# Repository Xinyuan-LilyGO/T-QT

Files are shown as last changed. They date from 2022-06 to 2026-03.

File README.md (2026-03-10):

<h1 align = "center"> 🌟T-QT🌟</h1>

## Description

T-QT is a development board whose main control chip is ESP32-S3. It is equipped with a 0.85-inch LCD color screen and two programmable buttons. Retains the same layout design as T-Display. You can directly use ESP32S3 for USB communication or programming.

***
## Pinmap

!!! There are currently two chip versions, using ESP32S3-FN4R2 (4MB Flash, 2MB PSRAM) and ESP32S3-N8 (8MB Flash, No PSRAM), the following only shows the pin diagram of N4R2, and the pin diagram of N8 is the same.

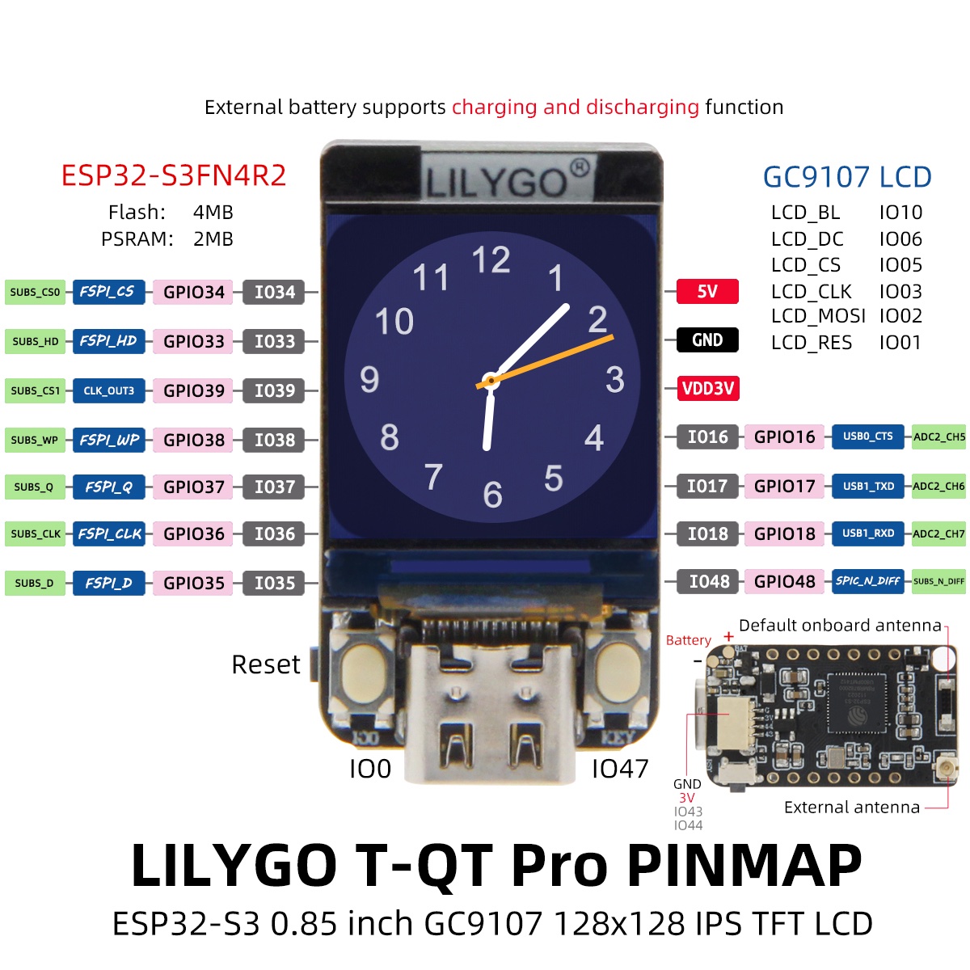
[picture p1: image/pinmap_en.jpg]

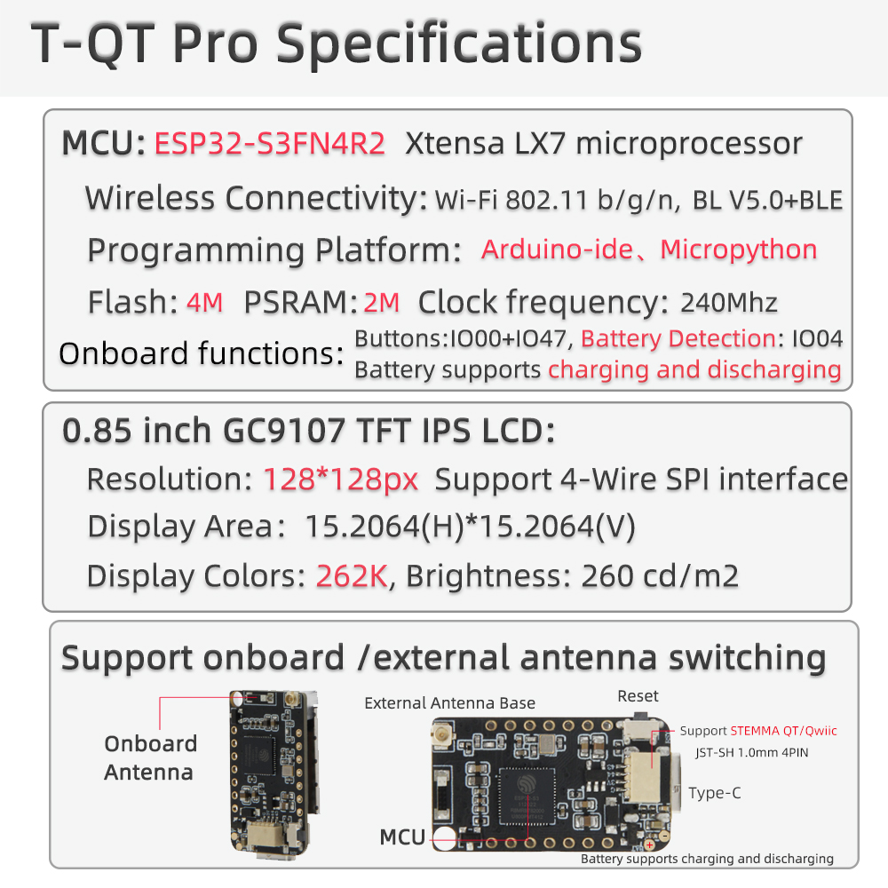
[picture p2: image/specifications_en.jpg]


***
<h3 align = "left">Product 📷:</h3>

| Product  | Product Link |
| :---: | :---: |
| T-QT Pro | [AliExpress](https://www.aliexpress.com/item/1005004405292321.html) |
| T-QT Pro | [LilyGo](https://www.lilygo.cc/products/t-qt-pro) |

***
## Quick Start

> Arduino:
1. In Arduino Preferences, on the Settings tab, enter the `https://raw.githubusercontent.com/espressif/arduino-esp32/gh-pages/package_esp32_index.json` URL in the `Additional boards manager URLs` input box. **Please pay attention to the version. The test phase is using 2.0.14. It is not certain that versions above 2.0.14 can run. When the operation is abnormal, please downgrade to a version below 2.0.14.** , As of 2024/08/02, TFT_eSPI does not work on versions higher than 2.0.14, see [TFT_eSPI/issue3329](https://github.com/Bodmer/TFT_eSPI/issues/3329)
2. Click OK and the software will install. 
3. Search for ESP32 in Tools → Board Manager and install ESP32-Arduino SDK (version 2.0.3 or above)
4. Copy everything from this repository lib folder to [Arduino library folder](https://docs.arduino.cc/software/ide-v1/tutorials/installing-libraries#manual-installation) (e.g. `C:\Users\YourName\Documents\Arduino\libraries`)
5. Select the correct settings in the Tools menu as shown below.

    ### K192,H579,H590 , 4M Flash , 2M PSRAM

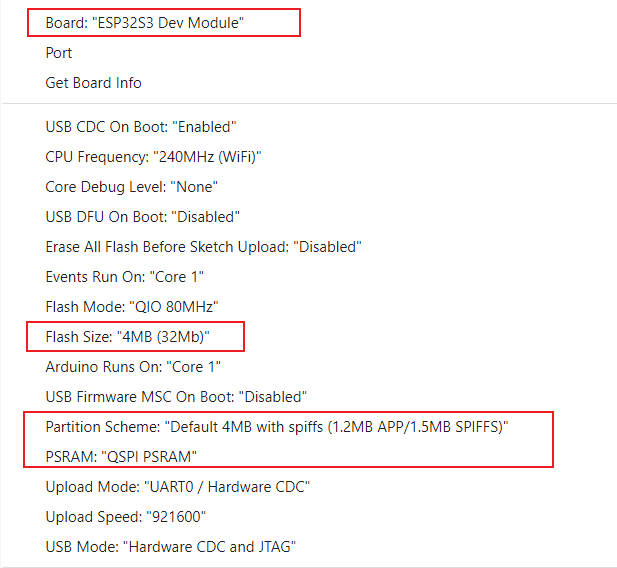
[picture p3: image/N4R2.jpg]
    

    ### K191,H628,H588 , 8M Flash ,No PSRAM

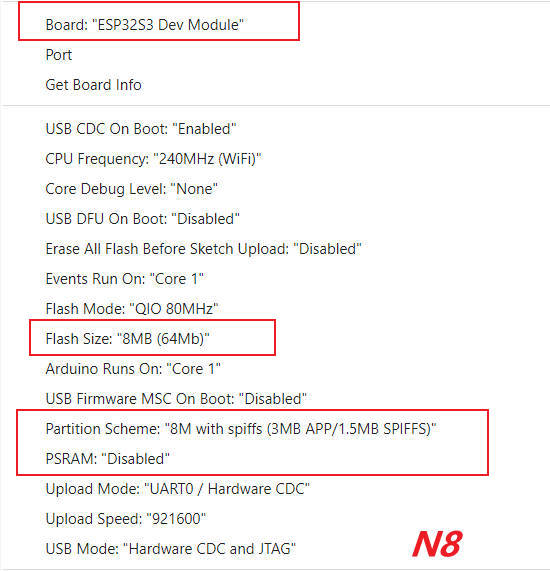
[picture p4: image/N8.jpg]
    

> PlatfromIO:
> - PlatformIO plug-in installation: Click on the extension on the left column -> search platformIO -> install the first plug-in
> - Click Platforms -> Embedded -> search Espressif 32 in the input box -> select the corresponding firmware installation

> ESP-IDF:
> - The installation method is also inconsistent depending on the system, it is recommended to refer to the [official manual](https://docs.espressif.com/projects/esp-idf/en/latest/esp32/get-started/index.html) for installation

***
## Quick question and answer

1. Does the onboard lithium battery charge function?
   - The old version T-QT does not support charging
   - The version on sale T-QT Pro supports charging function

2. Is it normal for the chip to continue to heat up during use?
   - The ESP32S3 will continue to heat up during use. Due to the small size of the baseboard, the heat of the ESP32S3 cannot be dissipated in time, so the overall temperature is stable at about 50-60 degrees Celsius. This temperature does not affect the normal use of the chip.

3. Unable to write?
   -  Press and hold the BOOT button on the board (located on the left side of the front of the screen), keep it tight, then plug in the USB and click to upload the sketch

## Tips

- The program can be written normally, but there is still no display after writing
    1. There are factory test files in the firmware folder, which can be flashed into the board to check whether the board is normal. If there is still no display, then it can be judged that there is a problem with the board or the screen
    2. Delete the <TFT_eSPI> in the libraries, and replace the <TFT_eSPI> in the <lib> folder of the main page to the libraries directory
    3. When opening the Arduino IDE, it prompts whether to upgrade the library, please choose not to upgrade, otherwise it will overwrite the configuration of the <TFT_eSPI> display

- Please note that the current use is a copy of TFT_eSPI, the screen initialization parameters have been modified, if you use the initialization parameters of the main line branch, the screen will not be clear

- QT currently sells two types of displays. The default configuration in lib/TFT_eSPI is the latest version. If you encounter display issues, please switch to the previous version's configuration:
- Here are the replacement steps: 

- Old panel
  1. Copy extras/old_panel/GC9A01_Init.h to lib/TFT_eSPI/TFT_Drivers. When prompted to overwrite, select yes. This will revert the display configuration to the old version initialization.
  2. Copy extras/old_panel/GC9A01_Rotation.h to lib/TFT_eSPI/TFT_Drivers. When prompted to overwrite, select yes. This will revert the display configuration to the old version initialization.

- New panel
  1. Copy extras/new_panel/GC9A01_Init to lib/TFT_eSPI/TFT_Drivers. When prompted to overwrite, select yes. This will revert the display configuration to the new version initialization.
  1. Copy extras/new_panel/GC9A01_Rotation to lib/TFT_eSPI/TFT_Drivers. When prompted to overwrite, select yes. This will revert the display configuration to the new version initialization.

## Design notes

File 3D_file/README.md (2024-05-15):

# This is 3D Shell File

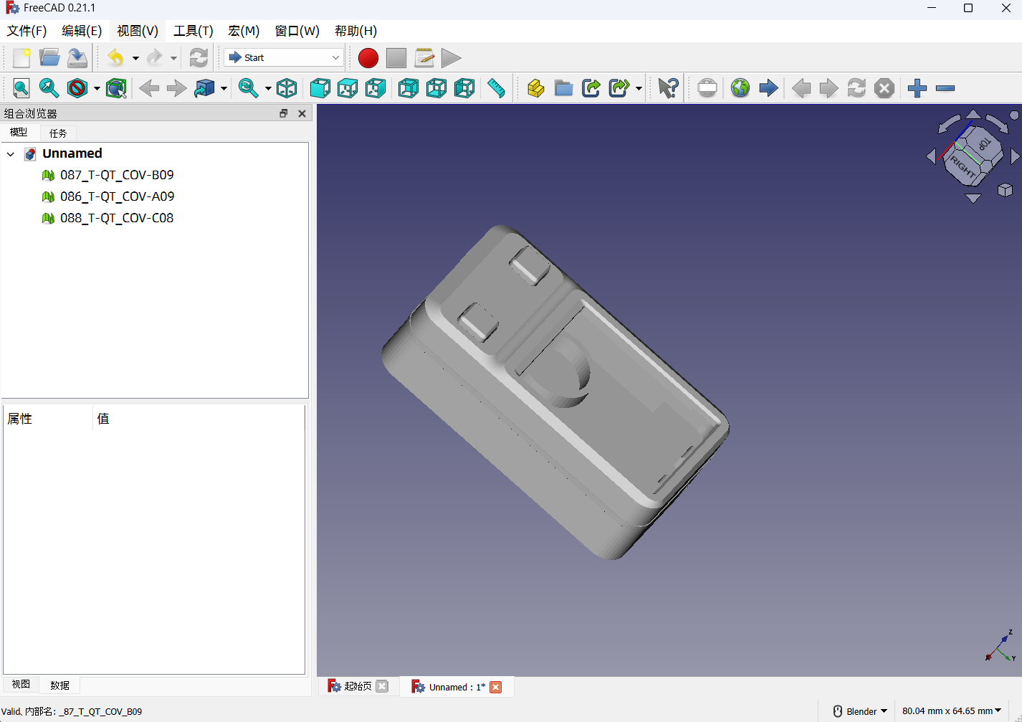
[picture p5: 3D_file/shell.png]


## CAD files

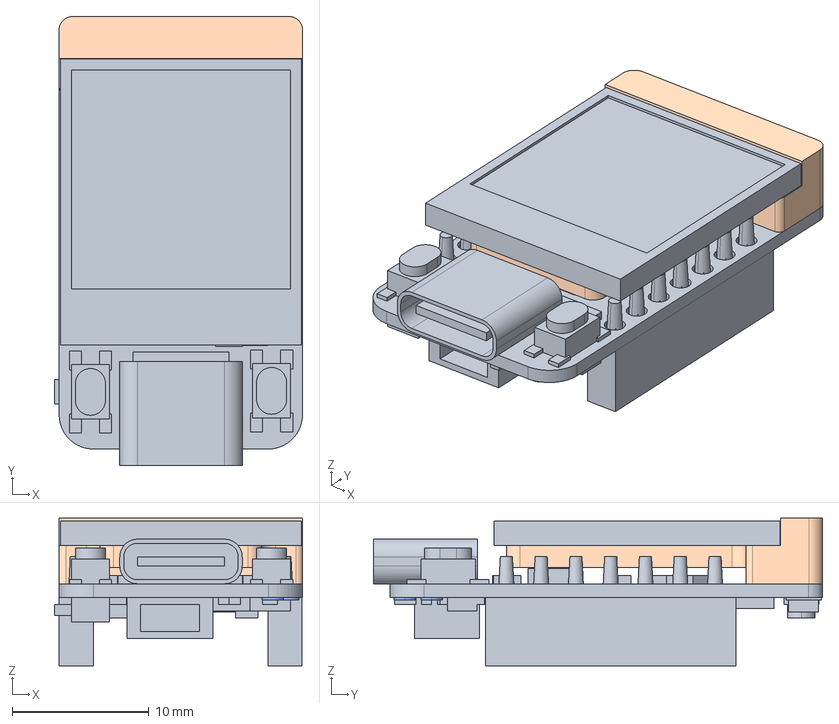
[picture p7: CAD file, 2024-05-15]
3D_file/T_QT_Pro.stp
18.1 x 32.8 x 10.8 mm
T_Q1T-PCB
050_T_Q1T-PMMA-COV5
T-Q1T-LCD
T_Q1T-PCB-00

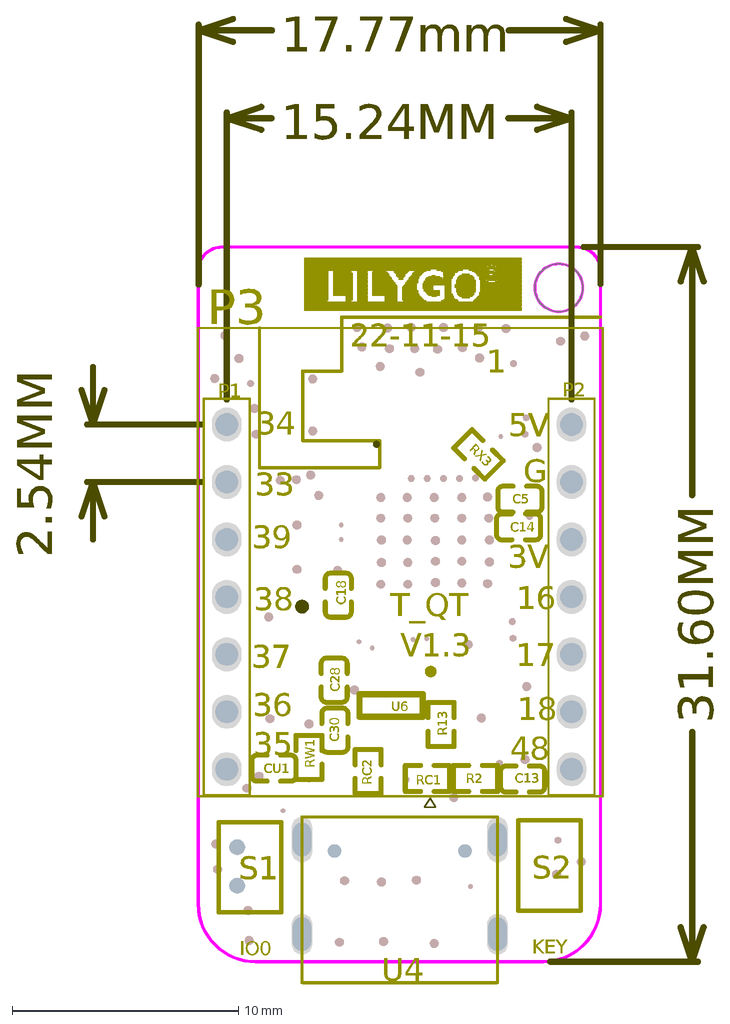
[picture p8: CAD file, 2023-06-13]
3D_file/T_QT.DXF
22-11-15
V1.3
T_QT
KEY
IO0
1
34
33
39
38
37
36
35
5V
G
3V
16
17
18
48
2.54MM
31.60MM
17.77mm
15.24MM
P2
P1
U4
S2
S1
RX3
RW1
R2
CU1
C18
C14
C13
C5
C28
C30
U6
P3
R13
RC1
RC2

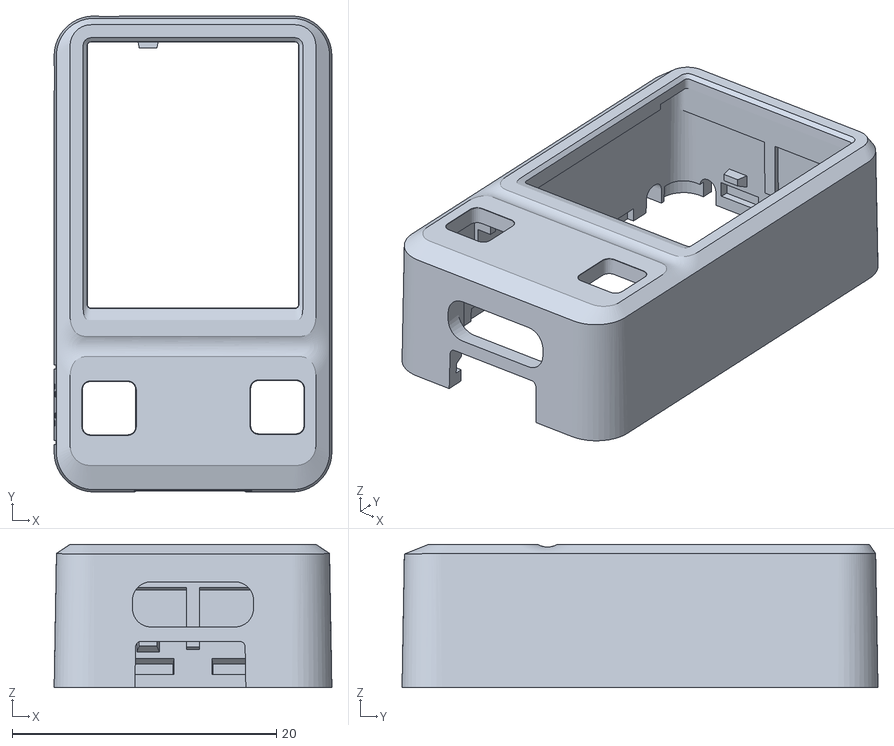
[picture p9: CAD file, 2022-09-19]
3D_file/086_T-QT_COV-A09.stl
21.0 x 36.0 x 10.9

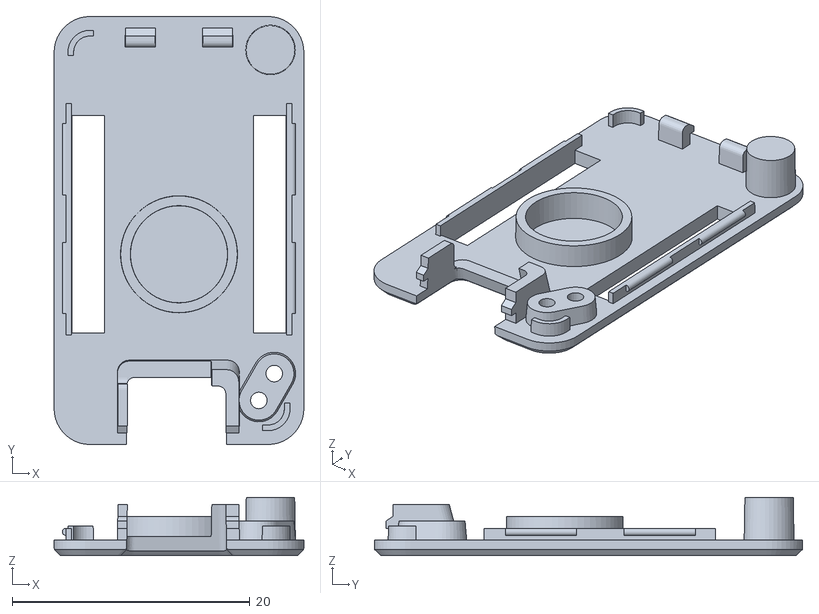
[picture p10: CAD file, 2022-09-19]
3D_file/087_T-QT_COV-B09.stl
21.0 x 36.0 x 4.90

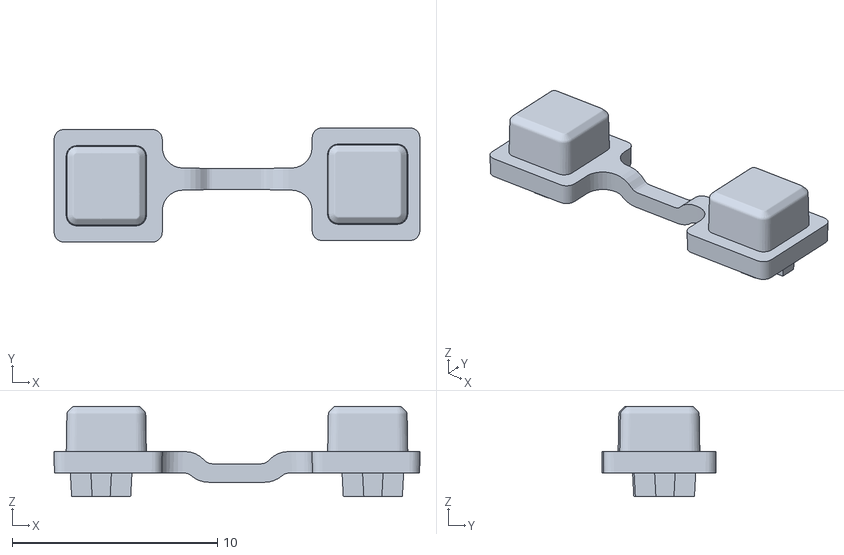
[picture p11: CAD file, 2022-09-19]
3D_file/088_T-QT_COV-C08.stl
17.8 x 5.57 x 4.40

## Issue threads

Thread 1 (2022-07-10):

There's no units available anywhere!

Sarah-C, 2022-07-10:
What happened?

We've got the code here, (thanks!) but the device is no longer available.  =(

Sarah-C, 2022-07-11:
I can't find the T-QT anywhere online anymore. It's only been for sale a short time.

You don't happen to know a link I can use to buy it, do you?

Sarah-C, 2022-07-12:
https://www.aliexpress.com/item/1005004405292321.html

Finally - they're back in stock today!

Closed 2022-07-12.

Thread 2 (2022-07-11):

Board Manager URL  error

Vadimledyaev, 2022-07-11:
Hi, Arduino ide can not load your boards package :
https://raw.githubusercontent.com/espressif/arduino-esp32/gh-pagespackage_esp32_index.json

This url leads to **400: Invalid request** page

What is the correct url?
Thanks

LilyGO, 2022-07-13:
The URL in the description may have expired, please use a new URL

https://raw.githubusercontent.com/espressif/arduino-esp32/gh-pages/package_esp32_index.json

Vadimledyaev, 2022-07-14:
Thanks! The guide does not say which board should I choose?
There are plenty of boards available from the list **Tools - Boards - ESP32 -** .
Which one is yours?

Sarah-C, 2022-07-24:
It'll be the : ESP32-S3 Dev Board         

[Vadimledyaev](https://github.com/Vadimledyaev), be careful with the libraries!    
TFT_eSPI's current version does NOT compile with the Factory demo. 

For me, I don't use the library else where, so I just deleted it from my library folder, and copied https://github.com/Xinyuan-LilyGO/T-QT/tree/main/lib libraries into my lib folder.      

The alternative is a bit messier - copying the libraries from this github into the sketch Factory folder, flat. No subfolders. Then you can use the up to date versions in your other libraries.

I don't know what changed so much to break it - I didn't spend time looking at the errors. =/

JpEncausse, 2022-07-30:
Hi,
There is no ESP32-S3 Dev Board I choose Dev Module but got `Error compiling for board ESP32S3 Dev Module` I correctly copy /lib to Arduino /librairies folder
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

Sarah-C, 2022-07-31:
My mistake, as you saw, it's "Module"

@JpEncausse
"Error compiling for board ESP32S3 Dev Module"..... there'll be more red/error text further up the text box. Can you dig it out? It'll detail file file name, line number, the line of code, and a little ^ arrow pointing to where it saw the issue.

JpEncausse, 2022-07-31:
Unfortunatly I didn't get more details, I assume it can't check for the given board,
Can you detail the Arduino option to set for T-QT ? (Memory, etc ...) to be sure I set evrything correctly (I tried many but still get the error)

LilyGO, 2022-08-02:
You just need to check "ESP32S3 Dev module" and the correct port. PSRAM needs to select OPI mode. Other configurations can be configured or set by default according to your project needs.

JpEncausse, 2022-08-02:
Ok so here is my configuration :

**OS**
- Windows 11
- Arduino 1.8.19
- Copy T-QT-main/lib/* into C:\Users\{name}\Documents\Arduino\libraries

First error : The Factory example didn't run because the script look for lv_conf.h that must be in /librairies/lv_conf.h I copy it from elswhere. Now it is fixed

**Arduino**
- Board : ESP32 Dev Module
- Upload Speed : 115200
- USB Mode : Hardware CDC and JTAG
- USB CDC On Boot : Disabled
- USB Firmware MSC On Boot : Disabled
- CPU Frequency : 240MHz (wifi)
- FlashMode : OPI 80MHz
- FlashSize : 8MB (64Mb)
- Partition Scheme : Default 4Mb with spiffs
- Core Debug Level : None
- PSRAM : OPI PSRAM
- Arduino Run on Core 1
- Events Run on Core 1
- Port COM4

Error 2 : So the `factory` and `lcd` script now compile but the board failed at reboot error with esptool (I assume the program is correctly write). On the board side, the screen stay black ...

LilyGO, 2022-08-05:
My mistake, I mistakenly thought this was a T-Display-S3. The PSRAM setting should be changed to QSPI or DISENABLE. (It depends on whether you bought the version with PSRAM or not). But selecting DISENABLE should be no problem.

LilyGO, 2022-08-05:
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

lynema, 2022-08-06:
After following this directions and compiling the factory example using the Arduino IDE and ESP32 library version 2.0.4, these lines are repeated over and over.

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

Board: ESP32S3 Dev Module
Libraries were copied from the demo so the TFT library has the right config
USB A to C cable was used as well.  The program uploaded.

Are there other settings that are missing that need to be set?

LilyGO, 2022-08-06:
Please try to use ESP32 library version 2.0.4. And execute the simplest blink program to test the hardware function of the board. If the blink program runs normally, please use this routine: https://github.com/Xinyuan-LilyGO/T-QT/tree/main/example/lcd @lynema

lynema, 2022-08-06:
@LilyGO
Tried this sketch with ESP32 library version 2.0.4.
```
void setup() {
	Serial.begin(115200);
}

void loop() {
	Serial.printf("Hello World");
	delay(3000);
}
```

Same thing happened.  The hardware is good.  When it was initially plugged in, the on-board display showed that it was attempting to connect to a wifi access point.

```
07:01:51.008 -> ESP-ROM:esp32s3-20210327
07:01:51.008 ->
07:01:51.115 -> ESP-ROM:esp32s3-20210327
07:01:51.115 -> Build:Mar 27 2021
07:01:51.115 -> rst:0x7 (TG0WDT_SYS_RST),boot:0x8 (SPI_FAST_FLASH_BOOT)
07:01:51.115 -> Saved PC:0x400454d5
07:01:51.148 -> SPIWP:0xee
07:01:51.148 -> mode:QIO, clock div:2
07:01:51.148 -> load:0x3fce3808,len:0x43c
07:01:51.148 -> ets_loader.c 78
```

lynema, 2022-08-07:
It works under platform.io with a couple edits.

These lines need to be altered to account for case sensitivity in https://github.com/Xinyuan-LilyGO/T-QT/blob/main/example/factory/platformio.ini
[env:esp32-s3-devkitc-1]
board = esp32-s3-devkitc-1
The board is esp32-s3-devkitc-1 which is different than what was mentioned above as the board name to try in the Arduino IDE. https://docs.platformio.org/en/latest/boards/espressif32/esp32-s3-devkitc-1.html

LilyGO, 2022-08-10:
@lynema Sorry, I rechecked my platformIO configuration. I am using arduino 2.0.3. version. Please recompile with this version.

LilyGO, 2022-08-10:
2.0.4 seems to have upgraded some features causing a reset, but I haven't checked its logs yet.

lynema, 2022-08-11:
@LilyGO Both
platform_packages = framework-arduinoespressif32@https://github.com/espressif/arduino-esp32.git#2.0.3
and
platform_packages =  framework-arduinoespressif32@https://github.com/espressif/arduino-esp32.git#2.0.4
worked ok for me.

Vadimledyaev, 2022-08-11:
After a few days of trying to hook the device up to my PC(Windows10,  Arduini IDE 2) without success (probably a problem with drivers but even Zadig couldn't fix that) I managed to make it on my laptop. After that I tried a pretty fresh windows 10 virtual machine under my main one and that works, too.

So after all Arduino is working, confirmed.

"SHA-256 comparison failed:" error is kinda normal:
```
SHA-256 comparison failed:
Calculated: 080c5cb68a075ced55f248b97bca965e3e5bd5da80a64e34e6a1638f89d6f64e
Expected: ffffffffffffffffffffffffffffffffffffffffffffffffffffffffffffffff
```

P.s, in case you haven't worked with lvgl lib like I haven't, To make it work you must copypaste lv_conf.h provided by LiLyGO to a LIB folder, do not leave it as is in  "lib/lvgl/"!

Sarah-C, 2022-08-20:
>P.s, in case you haven't worked with lvgl lib like I haven't, To make it work you must copypaste lv_conf.h provided by LiLyGO to a LIB folder, do not leave it as is in "lib/lvgl/"!

Good to know! Thanks!

I've had the exact same issue with a couple of other boards on my desktop Vs laptop. ....... how curious....

ChrisJones79, 2022-11-17:
Using the USB-OTG board works for me but I had to zip the lib I wanted to use and added the file image.h to the sketch

lewisxhe, 2023-03-29:
Not active for a long time, will be closed

ChrisJones79, 2023-03-29:
Ok

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

Closed 2023-03-29.

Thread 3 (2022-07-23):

../../lv_conf.h: No such file or directory

Sarah-C, 2022-07-23:
I've just run the "factory" example... and I get this:

            from C:\Users\sarah\Documents\Arduino\sketches\T-QT\factory\factory.ino:5:
c:\users\sarah\documents\arduino\libraries\lvgl\src\lv_conf_internal.h:41:18: fatal error: ../../lv_conf.h: No such file or directory
#include "../../lv_conf.h" /Else assume lv_conf.h is next to the lvgl folder/
^~~~~~~~~~~~~~~~~
compilation terminated.

Sarah-C, 2022-07-23:
Ah, I used the current lv library, I copied the one supplied in this code and it works fine.

Closed 2022-07-23.

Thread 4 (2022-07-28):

Bought 3 - 0 work

disruptivepatternmaterial, 2022-07-28:
Can someone tell me what the magic is to get these to work? I am using a Mac and tried multiple USB-C cables. None of the units power up or appear available in PIO.

What is the secret?

mgsb, 2022-07-28:
I had the same problem. What works for me is to use a USB-A cable on the host side, even if it means a USB-C/USB-A adaptor for the host. I asked elsewhere for LILYGO feedback but have not heard anything, yet.

LilyGO, 2022-08-02:
Please use a USBA-USBC cable. The use of USBC-USBC is not currently supported.

Closed 2022-08-10.

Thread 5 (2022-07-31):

Hour hand doesn't move as it should... fix included

Sarah-C, 2022-07-31:
If you're finding the hour hand in the factory demo to be a bit wonky... here's the fix.

The hour hand doesn't increment in fractions, so if it's 5 to 3, it looks almost like 5 to 2 because the hour hand hasn't moved on!

The fix shows the hour hand correctly positioned between two numbers for half past the hour:

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

The fix adds on the angle of the minutes scaled to 1/12 of a circle to the angle of the hour hand... which is simply multiplying the minutes by 5.

lvgl_gui.cpp
```
void update_sensor(lv_timer_t *timer) {
  float volt = (analogRead(PIN_BAT_VOLT) * 2 * 3.3) / 4096;
  char buf[20];
  snprintf(buf, 20, "bat_volt:%.2f V", volt);
  lv_label_set_text(bat_label, buf);

  struct tm timeinfo;
  if (getLocalTime(&timeinfo)) {
    // The line that fixes the hour hand.
    lv_img_set_angle(hour_img, ((timeinfo.tm_hour) * 300 + ((timeinfo.tm_min) * 5)) % 3600);
    lv_img_set_angle(min_img, (timeinfo.tm_min) * 60);
```

LilyGO, 2022-08-02:
thanks for your reminder.Please submit a pull request and I'll merge this.

Sarah-C, 2022-08-06:
https://github.com/Sarah-C/T-QT/commit/2980144b879a394d9c9399973fc774039b7895f6

[Micky513673326](https://github.com/Sarah-C/T-QT/commits?author=Micky513673326) has been nice enough to submit the pull request. Thank you!

Issue closed.

Sarah-C, 2022-08-06:
Closed!

Closed 2022-08-06.

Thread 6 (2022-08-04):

No CC Resistor

seldompopup, 2022-08-04:
Board connecting to USB-C port directly using USB-C to USB-C cable will not receive power.

LilyGO, 2022-08-05:
We also noticed issues with USBC. A fix for this resistor will be added in the next release.

Closed 2022-08-10.

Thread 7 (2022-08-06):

Waking up on right button - doesn't happen.

Sarah-C, 2022-08-06:
I see that the right button puts the device to sleep - which works fine.             
However I note that esp_sleep_enable_ext0_wakeup is used to set the wake button to the same right button.    
This doesn't work either via a build in Arduino (latest regular build) nor in PlatformIO - the device stays off.

I've no idea where the error is, it doesn't look like it's how it's being used here - perhaps Espressifs own code?      
I'm just raising this issue for others to know it's a "known issue" - and not this codes fault.

main.cpp:
```

void go_to_sleep(void) {
  Serial.println("sleep");
  digitalWrite(PIN_LCD_BL, HIGH);
  gpio_hold_en((gpio_num_t)PIN_LCD_BL);
  digitalWrite(PIN_LCD_RES, LOW);
  esp_sleep_enable_ext0_wakeup((gpio_num_t)PIN_BTN_R, 0);
  esp_light_sleep_start();
}
```

[What pins can wake the device.](https://docs.espressif.com/projects/esp-idf/en/v4.1/api-reference/peripherals/gpio.html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,DAC%2Fetc%20are%20in%20use.)

[The pins labelled RTC compatible.](https://docs.espressif.com/projects/esp-idf/en/latest/esp32s3/api-reference/peripherals/gpio.html)

The left button is GPIO 0, and the right is GPIO 47, so I originally thought it wasn't waking due to GPIO47 not being a RTC pin (and thus unable to wake the device) as shown in the article above.
I swapped the pin numbers in pin_config.h, because GPIO 0 IS connected to the RTC. But this failed to wake the device either.

```
#define PIN_BTN_L            47
#define PIN_BTN_R            0

```

Gargantuanman, 2022-10-14:
Im having the same issu thats because for some reason the PULL UP of the pin 0 fall when you send the controller to deepsleep that shouldnt be happening i believe there is some error on the schematic because supposely the button isn pulled up directly to regulator out, so it should be 3.3v always.

mmMicky, 2023-01-30:
As far as I know ESP32-S3 has this problem. You can use esp_sleep_enable_ext1_wakeup instead.

afpineda, 2023-02-09:
> Im having the same issu thats because for some reason the PULL UP of the pin 0 fall when you send the controller to deepsleep that shouldnt be happening i believe there is some error on the schematic because supposely the button isn pulled up directly to regulator out, so it should be 3.3v always.

Despite being externally pulled-up, maybe the GPIO is disabled before entering deep sleep mode. Check this code:

```c
void enterDeepSleep()
{
  // disable radios
  esp_bluedroid_disable();
  esp_bt_controller_disable();

  // Disable pins to avoid current drainage through pull resistors
  // Enable proper pull resistors for wake up (if available)
  for (int p = 0; p < GPIO_NUM_MAX; p++)
    if (GPIO_IS_VALID_GPIO((gpio_num_t)p) && !((p >= 6) && (p <= 11))) // Exclude flash memory pins
    {
      uint64_t pinBitmap = BITMAP(p);
      if (pinBitmap & ext1_wakeup_sources)
      {
        if (ext1_wakeup_mode == ESP_EXT1_WAKEUP_ANY_HIGH)
        {
          gpio_pullup_dis((gpio_num_t)p);
          gpio_pulldown_en((gpio_num_t)p);
        }
        else
        {
          gpio_pulldown_dis((gpio_num_t)p);
          gpio_pullup_en((gpio_num_t)p);
        }
      }
      else
      {
        gpio_pulldown_dis((gpio_num_t)p);
        gpio_pullup_dis((gpio_num_t)p);
      }
    }

  // enter deep sleep
  if (ext1_wakeup_sources != 0ULL)
  {
    ESP_ERROR_CHECK(esp_sleep_pd_config(ESP_PD_DOMAIN_RTC_PERIPH, ESP_PD_OPTION_ON));
    ESP_ERROR_CHECK(esp_sleep_enable_ext1_wakeup(ext1_wakeup_sources, ext1_wakeup_mode));
  } // else reset is required for wake up
  esp_deep_sleep_start();

  // should not enter here
  log_e("power::powerOff(): Deep sleep not working");
  delay(5000);
  ESP.restart();
}
```

`ext1_wakeup_sources` and `ext1_wakeup_mode` are global variables. `ext1_wakeup_sources` is a bitmap of configured GPIO numbers to be used for wake up.

```c
// Power management
static uint64_t ext1_wakeup_sources = 0;
static esp_sleep_ext1_wakeup_mode_t ext1_wakeup_mode = ESP_EXT1_WAKEUP_ANY_HIGH;
```

[Source code](https://github.com/afpineda/OpenSourceSimWheelESP32/blob/main/src/common/power.cpp)

lewisxhe, 2023-03-29:
I discovered this issue during yesterday's reorganization and has now fixed it

Sarah-C, 2023-06-27:
lewisxhe - this was a PCB routing change?

Closed 2023-03-29.

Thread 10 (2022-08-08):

Factory clock color

kirk5275, 2022-08-08:
How can I change the colors of the clock? Background, hands etc.?

kirk5275, 2022-08-09:
My Display is mostly gray with white letters. Second hand is yellowish orange.

LilyGO, 2022-08-09:
please attach your picture

kirk5275, 2022-08-09:
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

No matter what camera I use the is a blue tint to the picture. I see all gray with my eyes.

kirk5275, 2022-08-09:
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
Here is a better representation.

kirk5275, 2022-08-09:
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

LilyGO, 2022-08-10:
Abnormal display color is generally caused by several problems.
1. RGB and BGR display format settings are wrong.
2. The order of sending color buf is reversed.
3. The colors are set to invert.

  Select a normal color image to convert to an array and display the image using the provided TFT_eSPI library. If the display is normal, record the picture display format as RGB or BGR. reconstruct

kirk5275, 2022-08-10:
Just want to say that the duck looks okay. Green background white duck yellow beak and orange feet.

I am using your factory example with no modifications. Why should I have to change anything to get the colors to come out correctly? Also I don't know how to do do what you told me.

Again might I have a bad unit?

LilyGO, 2022-08-13:
If duck color is green background white duck yellow beak and orange feet. Then its color is normal.

kirk5275, 2022-08-15:
Okay. I might have wasted your time and you mine. The one with blue clock is in \T-QT-main\lib\TFT_eSPI\examples\Smooth Graphics\Anti-aliased_Clock.

LilyGO, 2022-08-15:
This obviously has nothing to do with the hardware. It may just be that a register needs to be modified during initialization or that it needs to be high first when sending color BUF.

kirk5275, 2022-08-15:
I am closing this as I don't have a color problem

Closed 2022-08-15.

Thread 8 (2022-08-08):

Programming with PlatformIO

kirk5275, 2022-08-08:
In order to program I have to hold reset, hold IO0, release IO0 and release IO0. Then click on the upload icon in PlatformIO to get it to program.

I have a ESPRESSIF ESP32-S3-DevKitC-1 board and I don't have to touch anything. PlatformIO works using the same code

LilyGO, 2022-08-09:
T-QT is uploaded via USB. If you want to view serial information through USB, you need to enable USB CDC on Boot in the Arduino configuration page. If you need to add a flag in platformIO:
build_flags =
     -DARDUINO_USB_MODE=1
     -DARDUINO_USB_CDC_ON_BOOT=1

kirk5275, 2022-08-09:
I'm sorry but that was not my question. I am talking about uploading code. To Upload I have to do the following:
1. Press and hold reset
2. Press and hold IO0
3. Release reset
4. Release IO0
5. Click on upload icon in PlatformIO

I do not have to do those steps if I use a  ESP32-S3-DevKitC-1 dev board from ESPRESSIF

I do see it executing a reset when it says connecting as my device does reboot. But it never goes into programming mode.

Uploading .pio\build\esp32-s3-devkitc-1\firmware.bin
esptool.py v3.3
Serial port com13
Connecting...  <-----------------------------------------------------------------**(RESETS HERE)**
Traceback (most recent call last):
Failed to get PID of a device on com13, using standard reset sequence.
  File "C:\Users\krkjc\.platformio\packages\tool-esptoolpy\esptool.py", line 5387, in <module>

    _main()
  File "C:\Users\krkjc\.platformio\packages\tool-esptoolpy\esptool.py", line 5380, in _main
    main()
  File "C:\Users\krkjc\.platformio\packages\tool-esptoolpy\esptool.py", line 4687, in main
    esp = esp or get_default_connected_device(ser_list, port=args.port, connect_attempts=args.connect_attempts,
  File "C:\Users\krkjc\.platformio\packages\tool-esptoolpy\esptool.py", line 115, in get_default_connected_device
    _esp.connect(before, connect_attempts)
  File "C:\Users\krkjc\.platformio\packages\tool-esptoolpy\esptool.py", line 664, in connect
    last_error = self._connect_attempt(mode=mode, usb_jtag_serial=usb_jtag_serial, extra_delay=extra_delay)
  File "C:\Users\krkjc\.platformio\packages\tool-esptoolpy\esptool.py", line 629, in _connect_attempt
    self.sync()
  File "C:\Users\krkjc\.platformio\packages\tool-esptoolpy\esptool.py", line 519, in sync
    val, _ = self.command(self.ESP_SYNC, b'\x07\x07\x12\x20' + 32 * b'\x55',
  File "C:\Users\krkjc\.platformio\packages\tool-esptoolpy\esptool.py", line 458, in command
    self.write(pkt)
  File "C:\Users\krkjc\.platformio\packages\tool-esptoolpy\esptool.py", line 421, in write
    self._port.write(buf)
  File "C:\Users\krkjc\.platformio\penv\lib\site-packages\serial\serialwin32.py", line 325, in write
    raise SerialTimeoutException('Write timeout')
serial.serialutil.SerialTimeoutException: Write timeout
*** [upload] Error 1
========================================== [FAILED] Took 101.61 seconds ==========================================

 *  The terminal process "C:\Users\krkjc\.platformio\penv\Scripts\platformio.exe 'run', '--target', 'upload'" terminated with exit code: 1.
 *  Terminal will be reused by tasks, press any key to close it.

LilyGO, 2022-08-10:
When you turn on the USB-CDC feature in settings. The next uploader can continue to use the port without pressing the button again. I have tested this function. The premise requires that you turn on the USB CDC on Boot function and do not use this pin in the program.

kirk5275, 2022-08-10:
I have these set in Platform.ini
build_flags =
    ;-DARDUINO_USB_MODE=1
    ;-DARDUINO_USB_CDC_ON_BOOT=1

I am trying to upload the factory (clock) example. It does NOT work. I get the error in my previous post.
Using those settings does enable the Serial Monitor to work.

I am the one that is also having color issues. Could I have  bad hardware?

kirk5275, 2022-08-15:
Anything movement on this issue of not having to press buttons to upload in PlatformIO?

LilyGO, 2022-08-15:
I didn't need to press IO0 for every download like you did during PlatformIO development. I have stated that this flag needs to be added and do not do anything with the USB pins in the code.

build_flags =
-DARDUINO_USB_MODE=1
-DARDUINO_USB_CDC_ON_BOOT=1

If you think the board has a color problem. Please upload a TFT example and upload a picture for me to observe.

kirk5275, 2022-08-15:
I found I don't have a color problem the factory clock is only gray background.

I have set the build flags to what you told me. I am not doing anything with the USB pins. Like I said I can see the device doing a reset when it says connecting.

I have attached the simplest program to output on the serial port "Testing". It does not upload without me pressing buttons.

If you have a sketch you want me to try I will
[upload test.zip](https://github.com/Xinyuan-LilyGO/T-QT/files/9335727/upload.test.zip)
.

kirk5275, 2022-08-15:
I also tried the same code with Aurduino IDE with the following settings and it won't upload either

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

Sketch uses 233217 bytes (17%) of program storage space. Maximum is 1310720 bytes.
Global variables use 13152 bytes (4%) of dynamic memory, leaving 314528 bytes for local variables. Maximum is 327680 bytes.
esptool.py v3.3
Serial port COM13
Connecting...Traceback (most recent call last):
  File "esptool.py", line 5387, in <module>
  File "esptool.py", line 5380, in _main
  File "esptool.py", line 4687, in main
  File "esptool.py", line 115, in get_default_connected_device
  File "esptool.py", line 664, in connect
  File "esptool.py", line 629, in _connect_attempt
  File "esptool.py", line 519, in sync
  File "esptool.py", line 458, in command
  File "esptool.py", line 421, in write
  File "serial\serialwin32.py", line 325, in write
serial.serialutil.SerialTimeoutException: Write timeout
[26460] Failed to execute script 'esptool' due to unha
ndled exception!
Failed uploading: uploading error: exit status 1

Sarah-C, 2022-08-20:
The T-QT device works correctly when commanded to reset. I can confirm it works with PlatformIO:
```
Building .pio\build\adafruit_feather_esp32s3_nopsram\firmware.bin
esptool.py v3.3
Creating esp32s3 image...
Merged 2 ELF sections
Successfully created esp32s3 image.
Configuring upload protocol...
AVAILABLE: cmsis-dap, esp-bridge, esp-builtin, esp-prog, espota, esptool, iot-bus-jtag, jlink, minimodule, olimex-arm-usb-ocd, olimex-arm-usb-ocd-h, olimex-arm-usb-tiny-h, olimex-jtag-tiny, tumpa
CURRENT: upload_protocol = esptool
Looking for upload port...
Auto-detected: COM10
Forcing reset using 1200bps open/close on port COM10
Waiting for the new upload port...
Uploading .pio\build\adafruit_feather_esp32s3_nopsram\firmware.bin
esptool.py v3.3
Serial port COM24
Connecting...
Chip is ESP32-S3
Features: WiFi, BLE
Crystal is 40MHz
MAC: f4:12:fa:43:20:b4
Uploading stub...
Running stub...
Stub running...
Changing baud rate to 460800
Changed.
Configuring flash size...
Flash will be erased from 0x00000000 to 0x00003fff...
Flash will be erased from 0x00008000 to 0x00008fff...
Flash will be erased from 0x0000e000 to 0x0000ffff...
Flash will be erased from 0x002d0000 to 0x002f8fff...
Flash will be erased from 0x00010000 to 0x0005ffff...
Flash params set to 0x023f
Compressed 15008 bytes to 10328...
Writing at 0x00000000... (100 %)
Wrote 15008 bytes (10328 compressed) at 0x00000000 in 0.3 seconds (effective 344.9 kbit/s)...
Hash of data verified.
Compressed 3072 bytes to 128...
Writing at 0x00008000... (100 %)
Wrote 3072 bytes (128 compressed) at 0x00008000 in 0.1 seconds (effective 303.4 kbit/s)...
Hash of data verified.
Compressed 8192 bytes to 47...
Writing at 0x0000e000... (100 %)
Wrote 8192 bytes (47 compressed) at 0x0000e000 in 0.1 seconds (effective 486.7 kbit/s)...
Hash of data verified.
Compressed 165488 bytes to 106746...
Writing at 0x002d0000... (14 %)
Writing at 0x002d863e... (28 %)
Writing at 0x002ddbbf... (42 %)
Writing at 0x002e4585... (57 %)
Writing at 0x002ea540... (71 %)
Writing at 0x002efe98... (85 %)
Writing at 0x002f529d... (100 %)
Wrote 165488 bytes (106746 compressed) at 0x002d0000 in 1.9 seconds (effective 700.1 kbit/s)...
Hash of data verified.
Compressed 326224 bytes to 169379...
Writing at 0x00010000... (9 %)
Writing at 0x00020d00... (18 %)
Writing at 0x00029f32... (27 %)
Writing at 0x00031e71... (36 %)
Writing at 0x0003786b... (45 %)
Writing at 0x0003cc00... (54 %)
Writing at 0x00041ec5... (63 %)
Writing at 0x00047780... (72 %)
Writing at 0x00050fb2... (81 %)
Writing at 0x00057f07... (90 %)
Writing at 0x0005d9a0... (100 %)
Wrote 326224 bytes (169379 compressed) at 0x00010000 in 3.3 seconds (effective 779.5 kbit/s)...
Hash of data verified.

Leaving...
Hard resetting via RTS pin...
```

OP please check your device drivers, as the device correctly reboots into upload mode when commanded to by PlatformIO, without any user involvement.

kirk5275, 2022-08-20:
@Sarah-C Thanks for the suggestions. I tried it on a laptop computer and it worked. Play around with the USB drivers and got it working on the desktop computer.

LilyGO, 2022-08-22:
https://github.com/Xinyuan-LilyGO/T-QT/issues/8#issuecomment-1215669544
As your Arduino is set up, turn on CDC ON BOOT

kirk5275, 2022-08-22:
I tried it on a laptop computer and it worked. Played around with the USB drivers and got it working on the desktop computer.
FYI you don't need these flags to upload. Only for the Serial Monitor to work. I just tried it.

 ;-DARDUINO_USB_MODE=1
 ;-DARDUINO_USB_CDC_ON_BOOT=1

Everything is working okay.

Sarah-C, 2022-08-22:
You're welcome! Happy coding!

evlo, 2023-01-26:
So could I connect RX TX to the usb data lines, keep 5V and GND and usb to work with uart like that?

Closed 2022-08-20.

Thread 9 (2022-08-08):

Serial Monitor

kirk5275, 2022-08-08:
How do I get the serial monitor to work with PlatformIO?

Using this simple program:

void setup() {
	Serial.begin(9600);
}

void loop() {
	Serial.printf("Hello World");
	delay(3000);
}

I get this:
--- Terminal on COM13 | 9600 8-N-1
--- Available filters and text transformations: colorize, debug, default, direct, esp32_exception_decoder, hexlify, log2file, nocontrol, printable, send_on_enter, time
--- More details at https://bit.ly/pio-monitor-filters
--- Quit: Ctrl+C | Menu: Ctrl+T | Help: Ctrl+T followed by Ctrl+H
waiting for download

Works okay with ESPRESSIF ESP-S3-DevKitC-1 board.

kirk5275, 2022-08-09:
Found the answer

build_flags =
    -DARDUINO_USB_MODE=1
    -DARDUINO_USB_CDC_ON_BOOT=1

Closed 2022-08-09.

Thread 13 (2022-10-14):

display backlight doesent remain OFF when deepSleep

Gargantuanman, 2022-10-14:
Currently Im executing this piece of code:

 if (goToSleep) {
    //Serial.println("I need to Sleep");
    gfx->displayOff();
    digitalWrite(TFT_BL, HIGH); // turn  OFF
    ledcWrite(pwmLedChannelTFT, 255);           // brightness 0 - 255
    esp_deep_sleep_start();
  }

I noticed that the screen backlight turns off brieftly but when the micro sleeps it turn on again (only Back light) i believe is because of the default state of the pin is LOW, is therea a workaround this issue?

The battery will dryout quickly if the BL cannot turn off.

Gargantuanman, 2022-10-14:
SOLVED just included this library and used those two commands.

#include "esp_sleep.h"

if (goToSleep) {
    //Serial.println("I need to Sleep");
    gfx->displayOff();
    digitalWrite(TFT_BL, HIGH); // turn  OFF
    gpio_hold_en(GPIO_NUM_10);
    gpio_deep_sleep_hold_en();
    esp_deep_sleep_start();
  }

Closed 2022-10-14.

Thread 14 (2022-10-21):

Publish board settings for Arduino IDE

HowdyMoto, 2022-10-21:
Can you please publish what settings I should use here in the Arduino IDE?
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

LilyGO, 2022-10-26:
Just select ESP32-S3-DEV. Most of the other options vary based on individual usage.

mmMicky, 2022-11-23:
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

afpineda, 2023-02-09:
Note:

In order to **enter boot mode**, press and hold the `IO0` button while pressing the `RESET` button.

MichaelCastano, 2023-05-01:
> Note:
>
> If required, in order to **enter boot mode**, press and hold the `IO0` button while pressing the `RESET` button.

Had problems connection on Windows 11 and that one hint solved it for me in the end 👍  Thanks
On MacOs it worked right out of the box following the Lilygo instructions.

Closed 2023-03-29.

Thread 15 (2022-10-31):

T-QT Pro?

dskw, 2022-10-31:
Hi, I have noticed that a lot of stores offer a "T-QT Pro" version instead of V1.1.
The only difference I could find is this image:
https://ae01.alicdn.com/kf/S24bd6ed3ecd24f09878124b287e865efs.jpg_640x640Q90.jpg_.webp

Is there an updated repository for the Pro version?
What does "support charging" mean? Does it allow LiPo charging?

LilyGO, 2022-11-01:
>Is there an updated repository for the Pro version?
There are no new warehouses. They share a repository, the only difference is the difference in hardware (psram and flash size)

>What does "support charging" mean? Does it allow LiPo charging?
Yes, it supports lithium battery charging.

dskw, 2022-11-01:
Thank you for the clarification! I would suggest to add a short section to the readme.rm to describe the new version. The added lithium battery charging makes the board even more attractive! :)

Vadimledyaev, 2023-01-29:
Hi, what cha

Closed 2022-11-01.

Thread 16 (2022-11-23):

What settings for factory example?

matterbury, 2022-11-23:
With the default settings compilation fails with:
```
Sketch uses 1379037 bytes (105%) of program storage space. Maximum is 1310720 bytes.
Global variables use 41472 bytes (12%) of dynamic memory, leaving 286208 bytes for local variables. Maximum is 327680 bytes.
```
With Flash Size of 8MB (64 Mb) and Partition Scheme 8M with spiffs the device just crash reboots.

matterbury, 2022-11-23:
In fact it would be very helpful to have some idea of which examples work on the T-S3 board and what settings are needed for them. So far I'm about 3 for 8 working with the rest just blank screen or crash booting.

mmMicky, 2022-11-23:
T-QT is a flash size of 8M. T-QT PRO has 4M flash size and 2M PSRAM. You can set the partition table for storing programs slightly larger. E.g 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

mmMicky, 2022-11-23:
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

matterbury, 2022-11-23:
Thanks, but as far as I can tell the factory example just does not work on the T-S3.
Many of the TFT_ ones do so I can play with those.

mmMicky, 2022-11-24:
It works fine on my computer. I wonder why your run fails. I need to fix it.

mmMicky, 2022-11-25:
I suggest you take a screenshot of the error or setting. I can help you check the problem.

mmMicky, 2022-11-25:
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
Here you need to set none

matterbury, 2022-11-25:
I set PSRAM to none and all the other settings as you have above.
Here is a video of the device while uploading, then a flash of the previous (clock) app when it rebooted, then the apparent crash looping after booting: https://www.dropbox.com/s/mhblk9lckomdqxq/IMG_0240.MOV?dl=0

Thanks for your help.

mmMicky, 2022-11-26:
I thought you had a problem with the T-QT product. If you have a problem with T-Display-S3, you need to enable the PSRAM-OPI function. It is recommended that you clone the repository without modifying it and use platformIO to compile. Because I used this platform to make. So I recommend you to use it.

mmMicky, 2022-11-26:
I can put the tested binary bin firmware here for you to burn and test.
[bin.zip](https://github.com/Xinyuan-LilyGO/T-QT/files/10095440/bin.zip)

matterbury, 2022-11-26:
Thank you very much, OPI PSRAM did the trick!

Closed 2022-11-26.

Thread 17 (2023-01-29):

Qwiic connector's pinout is wrong.

tfuruha, 2023-01-29:
The pinout(and The GPIO numbers printed) of the Qwiic connector are wrong, unlike the connections on the schematic.
According to the [ESP32-S3 datasheet](https://github.com/Xinyuan-LilyGO/T-QT/blob/main/doc/esp32-s3_datasheet_en.pdf), U0TXD and GPIO43 and U0RXD and GPIO44 each share a pin.
On the [schematic](https://github.com/Xinyuan-LilyGO/T-QT/blob/main/schematic/T_QT.pdf), pin 3 of the Qwiic connector is connected to U0TXD (GPIO43), but printed as 44 on the board and [pinout](https://github.com/Xinyuan-LilyGO/T-QT/blob/main/image/pinmap_en.jpg).
I2C tests using the Qwiic connector also worked fine by setting SDA (3pin) to 43 and SCL (4pin) to 44.

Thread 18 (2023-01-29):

T-QT PRO circuit and charging IC

Vadimledyaev, 2023-01-29:
Hi,

1. what charging IC is used in PRO version?
2. What is the charging current limit? I think it should be set to something like 20-30mA. Otherwise, a small battery will not last long.
3. Can you update the schematic pdf and provide the printed circuit of the PRO version?

Thanks.

mmMicky, 2023-01-30:
The charging IC used is TP4065. The charging current is limited to 400-500mA. I can update the schematic PRO version.

Vadimledyaev, 2023-01-30:
Well that current will definitely kill a small (60-200mAh +) battery and probably may cause **fire** and **explosion** . I strongly do not suggest to use it with a 1000mAh or less battery. (which size is huge).

For those who wanted a wearable device - desolder TP4065 and replace it with LTC4054 which charges the battery with currents from 10mA to 150mA (with Rprog set to 1000/Icharge, Ω, so from 100KΩ to 33KΩ is ok)

Weird and dangerous decision. Not supposed to be used in a wearable device. Liligo should kick in his butt the person who made the update without letting the people know the current.

mmMicky, 2023-01-31:
Adjust the charging current if necessary. No need to replace the chip. Only the current limiting resistor needs to be replaced. It's not always at 500mA charge when charging. When the battery voltage reaches about 4V, it will enter the trickle charging state. For specific correlation curves, please refer to the manual.

Vadimledyaev, 2023-01-31:
> Adjust the charging current if necessary. No need to replace the chip. Only the current limiting resistor needs to be replaced. It's not always at 500mA charge when charging. When the battery voltage reaches about 4V, it will enter the trickle charging state. For specific correlation curves, please refer to the manual.

According datasheet, TP4065 Charging current is from 130mA to 1A. That means even if I replace the resistor, the charging current of 130mA is still too high for a small,  wearable device. It will destroy a 80mAh battery, sooner or later. But yeah, It might be ok for a big 200mAh ++ battery if you replace the resistor .

Vadimledyaev, 2023-03-01:
> The charging IC used is TP4065. The charging current is limited to 400-500mA. I can update the schematic PRO version.
HI, when would you update the schematic circuit?

lewisxhe, 2023-03-29:
Not active for a long time, will be closed

dskw, 2023-06-01:
> The charging IC used is TP4065. The charging current is limited to 400-500mA. I can update the schematic PRO version.

The schematic has not been updated, or anything else on the repo. It still does not even mention the QT-Pro and its charging capabilities.

@Vadimledyaev could you tell which resistor on the boards needs to be replaced and with which resistance or achieve 150mA charging current? I was not able to find an English manual for TP4065 yet ;(

lewisxhe, 2023-06-01:
@dskw  When I saw your message, I verified that there is indeed an error. I have changed the schematic diagram and related materials to T-QT Pro, and the different sizes of resistors I noted in the schematic diagram correspond to different charging currents. . PS: I am not the designer of T-QT, I have tried my best to make the schematic diagram easy to understand
https://github.com/Xinyuan-LilyGO/T-QT/blob/main/schematic/T-QT-Pro.pdf

dskw, 2023-06-01:
@lewisxhe ahh perfect, thank you :) You even included the resistor table <3

I've looked at both sides of my board and am even more confused now where that IC is supposed to be.
Looking under the LCD the label says it's a T_QT V1.3. Now I am trying to identify the RPROG location on the PCB.
I cannot find any IC on both sides that matches the 8-pin layout of the TP4065, only two ICs with 5 pins:
65b226 and 2U=D7C

Is v1.3 the "Pro" or are there more versions of the board around?
The Aliexpress page identifies the "Pro" based on the battery solder pad layout and going by that it should be a "Pro"

dskw, 2023-06-01:
You are a champ! Thank you so much, that was the information I was looking for!

dskw, 2023-06-01:
And even better, it is already at 10k per default, so the charging rate of V1.3 is at 130mA. No need to change anything for my 150mAh battery then

farwrc, 2023-12-19:
What is the battery specification for this board to charge direct from usb c?

Closed 2023-03-29.

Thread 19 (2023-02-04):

Directly Wired Power 24V - Advice about wiring to 5V/3.3V pin

tyeth, 2023-02-04:
Can I just chuck 5V +/-5% into the 5V pin? I want to power the T-QT Pro from 24V, so was going to use an AP63205 which seems to fit the bill. I would appreciate any advice in this respect. I am aware the 3.3v model may be more appropriate, and could be put into the 3.3V pin probably safely, but I want 5V for other projects so will buy a few and therefore 5volts is more useful.

afpineda, 2023-02-09:
As far as I know, there are two answers: YES and...NO

**NO**

The built-in power regulator allows any input voltage from +5V to +7V more or less (don't know the exact value). The greater the voltage, the higher the wasted power and the higher the dissipated heat. In your case, to add a second power regulator is twice the power waste and much more heat.  **Not recommended**

**YES**

Going from +24V down to +3V3 means a lot of heat and wasted power. However, if you have no choice, just ignore the built-in power regulator at all, since the AP63205 is +3V3 output-capable. Wire such an output to `VDD3V` and `GND` as usual. Leave ' 5V' unconnected.

Be warned: **never attach `5V` nor the USB cable along with the external power source at the same time** or you will damage the devkit board.

**This is just my opinion. Didn't test myself**

lewisxhe, 2023-03-29:
I fully agree with @afpineda 's opinion,

Closed 2023-03-29.

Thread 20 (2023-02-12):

Adjust Backlight

MikeyBigs, 2023-02-12:
Is the Backlight adjustable? If so could you give a example.

Vadimledyaev, 2023-02-16:
see the schematic. LCD_BL is IO10.

lewisxhe, 2023-03-29:
```
#include <Arduino.h>
int freq = 2000;
int channel = 0;
int resolution = 8;
const int led = 10;
void setup()
{

  ledcSetup(channel, freq, resolution);
  ledcAttachPin(led, channel);
}

void loop()
{
  for (int dutyCycle = 0; dutyCycle <= 255; dutyCycle = dutyCycle + 5)
  {
    ledcWrite(channel, dutyCycle);
    delay(20);
  }

  for (int dutyCycle = 255; dutyCycle >= 0; dutyCycle = dutyCycle - 5)
  {
    ledcWrite(channel, dutyCycle);
    delay(20);
  }
}
```

Closed 2023-03-29.

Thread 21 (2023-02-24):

GPIO19 and gpio20 marked as do not use in pin reference?

evlo, 2023-02-24:
Hi,

why is gpio 19 and 20 in pin reference documentation  marked as _"do not use"_?

I would like to pass uart on those pins using usb-c connector, is that a problem?

lewisxhe, 2023-03-29:
The default is to upload and print programs. If you use a serial port, you will not be able to upload sketches through USB

Closed 2023-03-29.

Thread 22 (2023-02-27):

Circuitpython Support - Requested USB PIDs done - Work In Progress

tyeth, 2023-02-27:
I'm desperately keen to have this board supported in Circuitpython.
I've gone and added USB PID's after noticing the T-EmbedS3 was recently added https://github.com/espressif/usb-pids/pull/80
I've also defined the pins and done a working build, but no display tested yet so still work in progress.

If anyone has a further along repo or wants to contribute or just follow along then feel free.
Due to the GC9107 not being identical to the ST7789, I've not even begun to play with initialisation and it may just require minor tweaks, but I've included some code duplicated from the adafruit reverse s3 tft board. A clear way forwards is to use  russhughes repo's for both the T-QT and T-DisplayS3 display drivers in micropython.

https://github.com/tyeth/circuitpython/tree/add-lilygo_ttgo_t-qt

Might save someone else a little time.

lewisxhe, 2023-03-29:
Thank you for your contribution

Closed 2023-03-29.

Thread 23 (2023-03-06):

Battery charger

ArielIntel, 2023-03-06:
Hi, I have the device with the buttery charger support but I don't see where I can connect the battery.
There is no dedicated plug.

Arielhh, 2023-03-06:
> Hi, I have the device with the buttery charger support but I don't see where I can connect the battery. There is no dedicated plug.

Sorry, i found it. No need to answe that

Closed 2023-03-29.

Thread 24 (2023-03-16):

I want to build this project under esp-idf,what can i do

weiqifa0, 2023-03-16:
hi,i want to build this under esp-idf

weiqifa0, 2023-03-16:
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

weiqifa0, 2023-03-28:
I can't use esp-idf driver the lcd

lewisxhe, 2023-03-29:
I cannot provide code that can be run directly The IDF example directory contains related examples of spi lcds. Please refer to their implementation methods

weiqifa0, 2023-03-29:
but under ardunio ,what project can i open ?

weiqifa0, 2023-03-30:
哥们，能不能加个微信？

weiqifa0, 2023-04-03:
哥们，微信能不能加一个？

郁闷少年O(∩_∩)O~~
***@***.***

&nbsp;

------------------&nbsp;原始邮件&nbsp;------------------
发件人:                                                                                                                        "Xinyuan-LilyGO/T-QT"                                                                                    ***@***.***&gt;;
发送时间:&nbsp;2023年3月30日(星期四) 上午7:00
***@***.***&gt;;
***@***.******@***.***&gt;;
主题:&nbsp;Re: [Xinyuan-LilyGO/T-QT] I want to build this project under esp-idf,what can i do (Issue #24)

哥们，示例我全部更新过了，你重新克隆仓库吧。

—
Reply to this email directly, view it on GitHub, or unsubscribe.
You are receiving this because you authored the thread.Message ID: ***@***.***&gt;

Closed 2023-03-29.

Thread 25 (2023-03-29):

Battery indicator and USB recognition for T-QT Pro

mrudick1, 2023-03-29:
Hello,

I would like to create a battery indicator that also recognizes if the T-QT Pro is plugged in and charging.  I've got the code sample from factory.ino which shows voltage from IO4, but that doesn't help recognize if the board is plugged in or not.  It also isn't a great indication of battery percentage left since it's nonlinear.

Does anyone have any example code on how to do this?

mrudick1, 2023-03-31:
Looking at the ESP32 doc, it looks like it's using GPIO19 for USB DM and GPIO20 for USB DP.  If plugged into my laptop I get an analogRead of GPIO19 that's <5 with no serial data.  When I use a charger/adapter to plug into and outlet, it looks like I get a steady reading of 4095 with or without a battery connected.  Now, I don't know if this is a suitable solution of inferring that a 4095 analog reading means the T-QT Pro is plugged in and presumably charging.

Any and all feedback is appreciated!

liangtongt, 2024-06-07:
where is the factory.ino? can you share it?

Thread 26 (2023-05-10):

Which pins should used or I2C?

ismailagir, 2023-05-10:
Which pins should be used for I2C , is there any pre-defined ?

mrudick1, 2023-05-11:
It depends.  You can use the onboard JST connector as a Stemma/Qwiic connection.  If you choose to do so, the pins are:

GND = GND
3V = 3V
GPIO 44 = SCL
GPIO 43 = SDA

If you don't use this connector and solder it yourself, you can use any of the available GPIO pins for SCL and SDA.

jims1234, 2023-06-15:
Is there a 10K or equivalent pull up resistor mounted on the board on the SCL and SDA pins? if not do I need to add them externally?

lewisxhe, 2023-06-15:
It is not necessary to use a sensor module, which is generally integrated on the module. If a separate sensor is used, it is necessary

icubex, 2023-12-11:
It seems that on https://github.com/Xinyuan-LilyGO/T-QT/blob/main/image/pinmap_en.jpg the texts "IO44" and "IO43" should be exchanged.

ubidefeo, 2024-04-11:
@icubex
I found out the same thing by just trying.

@icubex @mrudick1 I have opened #37 to address this

u.

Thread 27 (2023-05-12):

Stuck with this board

Chanete, 2023-05-12:
Hi, I'm stucked with this board, any help would be appreciate.

I've just bought 2 of thie tiny display from Ali, I've downloadad this repo and just tried to compile any of the samples to no avail.

To focus in one I've tried to compila and download the Arduino_Life proyect.

I've tried in Arduino Ide and in Platform IO with same results (nothing)

In Arduino IDE I just open the Arduino_Life.ino in samples dir. Select "ESP32S3-DevModule" board, select the proper com port and click upload. Everything goes great compiles, upload but, nothing happens. I've reset the device, power cyclo but nothing

If I try the same with platformio. there is a sligth difference, I've copied the esp-32-s3-qt-pro.json file to my boards dir. Then I compila and upload and sometimes it works, somtimes it stops around 40% of the upload.

can someone give a clue or a a project (easy, just "Hello world..") that runs on this device.  I must be doing something real wrong, but I'm stuckedd...

Thx on advenac

mrudick1, 2023-05-15:
First, to put the QT into bootloader mode,  press and hold the left button while you press and release the reset button.

For working code, start here:  https://github.com/Xinyuan-LilyGO/T-QT

All the example programs work.

369Martin369, 2023-05-25:
PSRAM disabled?
8MB Flash?

mrudick1, 2023-05-25:
That would depend on which QT Pro you have.  There's one with just 8MB Flash and another with 4MB Flash and 2MB PSRAM.  Partition scheme can be default.  Also make sure you enable USB CDC On Boot.

jims1234, 2023-06-15:
I'm very glad you posted these suggestions above.. especially about " to put the QT into bootloader mode, press and hold the left button while you press and release the reset button." I just compiled and ran my 1st example "Rainbow" demo.. and tho there were several IDE warnings. related to the TFT_eSPI, it did load and run. Thanks again

farwrc, 2023-12-14:
I have the same here buy on ali too, i done everything what it on git and nothing show on display and de serial monitor is in looping but i flash the firmware and this works but sketch none copile upload and nothing

lewisxhe, 2023-12-14:
Have you selected the correct configuration according to the README?
https://github.com/Xinyuan-LilyGO/T-QT?tab=readme-ov-file#quick-start

farwrc, 2023-12-14:
> Have you selected the correct configuration according to the README? https://github.com/Xinyuan-LilyGO/T-QT?tab=readme-ov-file#quick-start

Yes, i did, i try all sketchs in this repository and nothing display, this is the serial monitor after flash the board with the firmware found in this link

ESP-ROM:esp32s3-20210327
Build:Mar 27 2021
rst:0x15 (USB_UART_CHIP_RESET),boot:0x29 (SPI_FAST_FLASH_BOOT)
Saved PC:0x4209ad42
SPIWP:0xee
mode:DIO, clock div:1
load:0x3fce3808,len:0x43c
load:0x403c9700,len:0xbec
load:0x403cc700,len:0x2a3c
SHA-256 comparison failed:
Calculated: 3611f330726ad4edf64f62982b0568332a5800bc59425cab90be5379db92c108
Expected: ffffffffffffffffffffffffffffffffffffffffffffffffffffffffffffffff
Attempting to boot anyway...
entry 0x403c98d8
E (233) psram: PSRAM ID read error: 0x00ffffff
Hello T-QT
Chip: ESP32-S3
ChipRevision: 0
Psram size: 0KB
Flash size: 8192KB
scan done

mrudick1, 2023-12-14:
Any time I've had this happen it's one of three things:

1) The board settings
2) Making sure you've chosen the correct board firmware (ESP32S3 Dev Module)
3) The User_Setup.h file in the the TFT_eSPI library has not been properly modified.

farwrc, 2023-12-14:
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

What properly modification will need? copy the TFT_eSPI library from here

mrudick1, 2023-12-14:
When you update the TFT_eSPI library it overwrites what is there.  So your User_Setup.h file goes back to the default, which is not specific to the QT.  I suggest you update this library, then copy the /User_Setups/Setup211_LilyGo_T_QT_Pro_S3.h file to the root TFT_eSPI folder (one up) and then rename it to User_Setup.h.  Otherwise your code won't know what display you're using.

farwrc, 2023-12-14:
> When you update the TFT_eSPI library it overwrites what is there. So your User_Setup.h file goes back to the default, which is not specific to the QT. I suggest you update this library, then copy the /User_Setups/Setup211_LilyGo_T_QT_Pro_S3.h file to the root TFT_eSPI folder (one up) and then rename it to User_Setup.h. Otherwise your code won't know what display you're using.

Ok i wil try that, but i dont update the library when the IDE ask i chose later

mrudick1, 2023-12-14:
It's a good idea to update the library, since bodmer has done a lot of work on it.  He also includes a QT Pro specific setup file for us..
I do advice that you first work using the arduino IDE because it's simpler to get started.  Once you have things working there, you can use platformio so you can localize the libraries and not have these kinds of problems moving forward.

farwrc, 2023-12-14:
All right i trying get the things work but none of the examples are work even a "hello world" apears on the screen, the board is functional because the firmware flashs and work and i can see the logo os lilygo and them the round clock only that still work but nothing tha ia upload work .....sorry my poor english i am from brasil

mrudick1, 2023-12-14:
Your english is great.  Don't worry about that.

OK, if you're seeing the Liligo logo on the screen, then it's not the TFT library.  Are you using the arduino IDE?  Have you chosen the correct port on your computer that your QT is attached to?  And have you allowed that port to access your computer (Mac will ask you to choose).
When you try to compile and upload, do you see the compile output complete and the upload begin to the QT?  It sounds like your QT only has the factory sketch on it.  So it might not be uploading at all.

farwrc, 2023-12-14:
> Your english is great. Don't worry about that.
>
> OK, if you're seeing the Liligo logo on the screen, then it's not the TFT library. Are you using the arduino IDE? Have you chosen the correct port on your computer that your QT is attached to? And have you allowed that port to access your computer (Mac will ask you to choose). When you try to compile and upload, do you see the compile output complete and the upload begin to the QT? It sounds like your QT only has the factory sketch on it. So it might not be uploading at all.

Yes i using a arduino IDE and chose the correct port i am use a PC wih win 10 the compile and upload run fine them when reset the board nothing show up

farwrc, 2023-12-19:
> Your english is great. Don't worry about that.
>
> OK, if you're seeing the Liligo logo on the screen, then it's not the TFT library. Are you using the arduino IDE? Have you chosen the correct port on your computer that your QT is attached to? And have you allowed that port to access your computer (Mac will ask you to choose). When you try to compile and upload, do you see the compile output complete and the upload begin to the QT? It sounds like your QT only has the factory sketch on it. So it might not be uploading at all.

Well, I'm no longer stuck with this board, on an Arduino forum some information was very useful and functional, resolving all the problems, not using the latest version of Espressif board management, version 3 doesn't work, the one that was solved for me was 2.011, and using your informations combined with this everything worked perfectly

mrudick1, 2023-12-19:
I'm so glad everything is working now!  Welcome to the QT family.  It's a remarkable little board.

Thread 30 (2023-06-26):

Blank Screen

robcloot, 2023-06-26:
I can upload the following sketch, and the serial monitor works, but nothing displays on the T-QT screen.

#include <TFT_eSPI.h>
TFT_eSPI tft = TFT_eSPI();

void setup()
{
 Serial.begin(115200);
 tft.init();
 tft.fillScreen(TFT_BLACK);
}

void loop()
{
 tft.println("Hello World");
 Serial.println("Hello World");
 delay(1000);
 }

lewisxhe, 2023-06-27:
See [QuickStart](https://github.com/Xinyuan-LilyGO/T-QT/tree/f298282b1837a90fad4f1722d082405742ea0077#quick-start) and Tips

robcloot, 2023-06-28:
Yes lewisxhe, that fixed the problem.  I needed to  use the TFT_eSPI settings for T-QT in GitHub.  Thank you so much!

Closed 2023-06-28.

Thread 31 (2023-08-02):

Build Filesystem Image fails ...

githubgoucho, 2023-08-02:
the **factory sketch** build is OK, but the **filsystem build** reports error.
Data directory is there and not empty
any ideas?
Here is my output:

Processing T-QT-Pro-N8 (platform: espressif32; board: esp32-s3-t-qt-pro; framework: arduino)
--------------------------------------------------------------------------------------------------------------------------------------------------------------------------------------Verbose mode can be enabled via `-v, --verbose` option
CONFIGURATION: https://docs.platformio.org/page/boards/espressif32/esp32-s3-t-qt-pro.html
PLATFORM: Espressif 32 (6.3.2) > Espressif ESP32-S3-T-QT (4 MB QD, No PSRAM)
HARDWARE: ESP32S3 240MHz, 320KB RAM, 4MB Flash
DEBUG: Current (esp-builtin) On-board (esp-builtin) External (cmsis-dap, esp-bridge, esp-prog, iot-bus-jtag, jlink, minimodule, olimex-arm-usb-ocd, olimex-arm-usb-ocd-h, olimex-arm-usb-tiny-h, olimex-jtag-tiny, tumpa)
PACKAGES:
 - framework-arduinoespressif32 @ 3.20009.0 (2.0.9)
 - tool-esptoolpy @ 1.40501.0 (4.5.1)
 - tool-mkspiffs @ 2.230.0 (2.30)
 - toolchain-riscv32-esp @ 8.4.0+2021r2-patch5
 - toolchain-xtensa-esp32s3 @ 8.4.0+2021r2-patch5
Converting LVGL_Factory.ino
LDF: Library Dependency Finder -> https://bit.ly/configure-pio-ldf
LDF Modes: Finder ~ chain, Compatibility ~ soft
Found 37 compatible libraries
Scanning dependencies...
Dependency Graph
|-- lvgl @ 8.3.0-dev
|-- OneButton @ 2.0.3
|-- WiFi @ 2.0.0
|-- TFT_eSPI @ 2.5.23
Building in release mode
Building FS image from 'data' directory to .pio\build\T-QT-Pro-N8\spiffs.bin
error: can't read source directory
*** [.pio\build\T-QT-Pro-N8\spiffs.bin] Error 1

githubgoucho, 2023-08-03:
Thanks, that was the trick.

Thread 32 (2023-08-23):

A fatal error occurred: No serial data received.

robcloot, 2023-08-23:
After successfully uploading code to my T-QT board multiple times in the past few weeks, it suddenly stopped receiving uploads with a "No serial data received" error.  I uploaded the same code with the same cable to an identical board and it works fine.  Did I overwork or break the board?  Can I recover from this?  Here are the details.

Arduino: 1.8.19 (Linux), Board: "ESP32S3 Dev Module, Disabled, QSPI PSRAM, QIO 80MHz, 4MB (32Mb), Core 1, Core 1, Hardware CDC and JTAG, Enabled, Disabled, Disabled, UART0 / Hardware CDC, Default 4MB with spiffs (1.2MB APP/1.5MB SPIFFS), 240MHz (WiFi), 921600, None, Disabled"

Sketch uses 303305 bytes (23%) of program storage space. Maximum is 1310720 bytes.
Global variables use 20220 bytes (6%) of dynamic memory, leaving 307460 bytes for local variables. Maximum is 327680 bytes.
esptool.py v4.5.1
Serial port /dev/ttyACM0
Connecting...
Chip is ESP32-S3 (revision v0.1)
Features: WiFi, BLE
Crystal is 40MHz
MAC: f4:12:fa:a8:d3:e8
Uploading stub...
Running stub...
Stub running...
Changing baud rate to 921600

A fatal error occurred: No serial data received.
A fatal error occurred: No serial data received.

robcloot, 2023-08-24:
I fixed it by doing the following:
Press and hold the BOOT button on the board (located on the left side of the front of the screen), keep it tight, then plug in the USB and click to upload the sketch.

Closed 2023-08-24.

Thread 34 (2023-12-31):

Battery reading while charging & power off

mrudick1, 2023-12-31:
I have attached an on/off switch.  I'm unable to get the battery reading when the device is turned off and charging.  Here is the behavior:

1) Not charging & turned on, IO4 reading is correct.
2) Charging & turned on, IO4 reading is correct.
3) Charging & turned OFF, IO4 reading shows full battery.

So it looks like IO4 gives me the charging voltage when turned off, not the battery voltage.  I need to get the battery voltage so I can display the device charging.

How can I do this?

lewisxhe, 2024-10-14:
When charging, the charging voltage is obtained, and the battery voltage cannot be obtained.

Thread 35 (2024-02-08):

USB MIDI device

aberoev, 2024-02-08:
Hi, trying to make a USB MIDI device out of this board, but can't seem to make it appear as one using [Control-Surface lib](https://github.com/tttapa/Control-Surface/tree/main)

I'm using the dev core arduino 3.0 choosing ESP32S3_USB-OTG

Also tried [this example](https://github.com/esp32beans/ESP32USBMIDI/blob/main/examples/ESP32USBMIDI/ESP32USBMIDI.ino), compiles and uploads fine, but no USB MIDI device

Any hints?

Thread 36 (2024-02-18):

I2S interrupt errors

RWLakloplak, 2024-02-18:
While other S3 and C3 boards seem to work well with am INMP441 mic, it seems to throw interrupt errors with this specific board, regardless what pins I define.

lewisxhe, 2024-10-14:
Paste your test code

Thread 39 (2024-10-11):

LVGL Factory example issue

JackIsGoofingOff, 2024-10-11:
Hi, I am here to seek for some helps about the lvgl factory example. I just ran the LVGL Factory example from the T-QT official folder and nothing wrong was reported from Serial Monitor. But the screen paused completely after a few seconds of running the wifi clock which I guess was related the following codes. May I know the possible reasons for it?
`
gui_init();
    while (1) {
      lv_timer_handler();
    }
`

lewisxhe, 2024-10-12:
The clock pause may be related to the wifi connection. Are you sure you are connected to the correct wifi?
https://github.com/Xinyuan-LilyGO/T-QT/blob/3f31e59a84d4530e26c236faab19391f80827593/examples/LVGL_Factory/lvgl_gui.cpp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

JackIsGoofingOff, 2024-10-12:
In the screen it shows that wifi has been connected and the clock actually can run for a few seconds

lewisxhe, 2024-10-14:
Try pressing the button to see if the page switches!

OomNiel, 2024-12-01:
Fix regarding this issue:

in 'void update_sensor(lv_timer_t *timer)' function:- comment out the line: 'if (!WiFi.isConnected())return;'
The WiFi will disconnect when time is retrieved from the NTP server.
This is set up in function: void timeavailable(struct timeval *t)
I presume this is done in order to prevent the application from spamming the NTP server with requests.

Also:
IF using the old T-QT board, add: '#define USE_HSPI_PORT' in the  'Setup211_LilyGo_T_QT_Pro_S3.h' file.
It seems that the board use the alternative HSPI spi port for driving the lcd.

The published example was obviously not tested for using on the old board.

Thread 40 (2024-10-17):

USB host power

icubex, 2024-10-17:
I want to use the USB port in host mode. How can I set the USB connector to supply power when in USB host mode ? If not in software, how could I modify the board so that the USB port supplies power ? I am supplying power to the board via the 5V pin and don't need the battery feature.

lewisxhe, 2024-10-18:
It is not necessary to use battery power. The 5V pin interface and USB 5V are the same line. You can connect 5V from the 5V pin, so USBC will also have 5V output.

icubex, 2024-10-18:
I don't get any power from the USBC port after applying 5V to the 5V pin. The 3V3 pin provides 3V3 and the board is working correctly it seems because the loaded sketch is outputting data as expected. Are you sure the 5V pin is the same as the USBC 5V ? For reference I ran the same sketch on a ESP32S3 supermini board and its USBC port does provide power.

lewisxhe, 2024-10-18:
Oh! Sorry, the QT has a voltage switching function, so you can't use this function without removing the original part. If you need to transfer 5V to USB 5V, you need to short-circuit the diode D3.
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

icubex, 2024-10-18:
Excellent, it works. Thanks for the help !

Closed 2024-10-21.

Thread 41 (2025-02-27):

How is the 3.7v-4.2v from LiPo battery is getting converted into 3.3v

jaswch, 2025-02-27:
Hello all,
I'm an amateur in PCB designing and I'm creating a PCB which involves an ESP32 S3 WROOM 1 which can be powered by both LiPo and USB, I've looked at the schematics for the TQT Pro for reference but only 5V is passed through the RT9080 LDO, the only place where I see VBAT being connected is TP4056B, a MOSFET and a voltage divider. So could you guys please help me that do I need to connect VBAT to the LDO?

Thanks in advance for any help!

Closed 2025-03-01.

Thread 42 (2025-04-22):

T-QT pro + mpu6050 I2C

dim3w, 2025-04-22:
HI, I have no I2c address when I connect mpu6050(gy521) sensor on pins 43 and 44 (Qwiic) on my nano board no problem, why I2C not working?

dim3w, 2025-04-22:
I solved I2C address with Wire():

#include <Wire.h>
#include <basicMPU6050.h>

#define I2C_Freq 100000
#define SDA_0 43 //_______________________DEFINE PINS SDA
#define SCL_0 44 //________________________DEFINE PINS SCL

// Create instance
basicMPU6050<> imu;

void setup() {
  Wire.begin(SDA_0 , SCL_0 );//___________________ INIT WIRE
  // Set registers - Always required
  imu.setup();

  // Initial calibration of gyro
  imu.setBias();

  // Start console
  Serial.begin(38400);
}

void loop() {
  // Update gyro calibration
  imu.updateBias();

  //-- Scaled and calibrated output:
  // Accel
  Serial.print( imu.ax() );
  Serial.print( " " );
  Serial.print( imu.ay() );
  Serial.print( " " );
  Serial.print( imu.az() );
  Serial.print( "    " );

  // Gyro
  Serial.print( imu.gx() );
  Serial.print( " " );
  Serial.print( imu.gy() );
  Serial.print( " " );
  Serial.print( imu.gz() );
  Serial.print( "    " );

  // Temp
  Serial.print( imu.temp() );
  Serial.println();
}

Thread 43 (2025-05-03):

Solder the pins

dim3w, 2025-05-03:
Is it possible to remove the screen in order to solder the pins?
Thanks

lewisxhe, 2025-05-05:
Yes, provided you don't short-circuit these pins

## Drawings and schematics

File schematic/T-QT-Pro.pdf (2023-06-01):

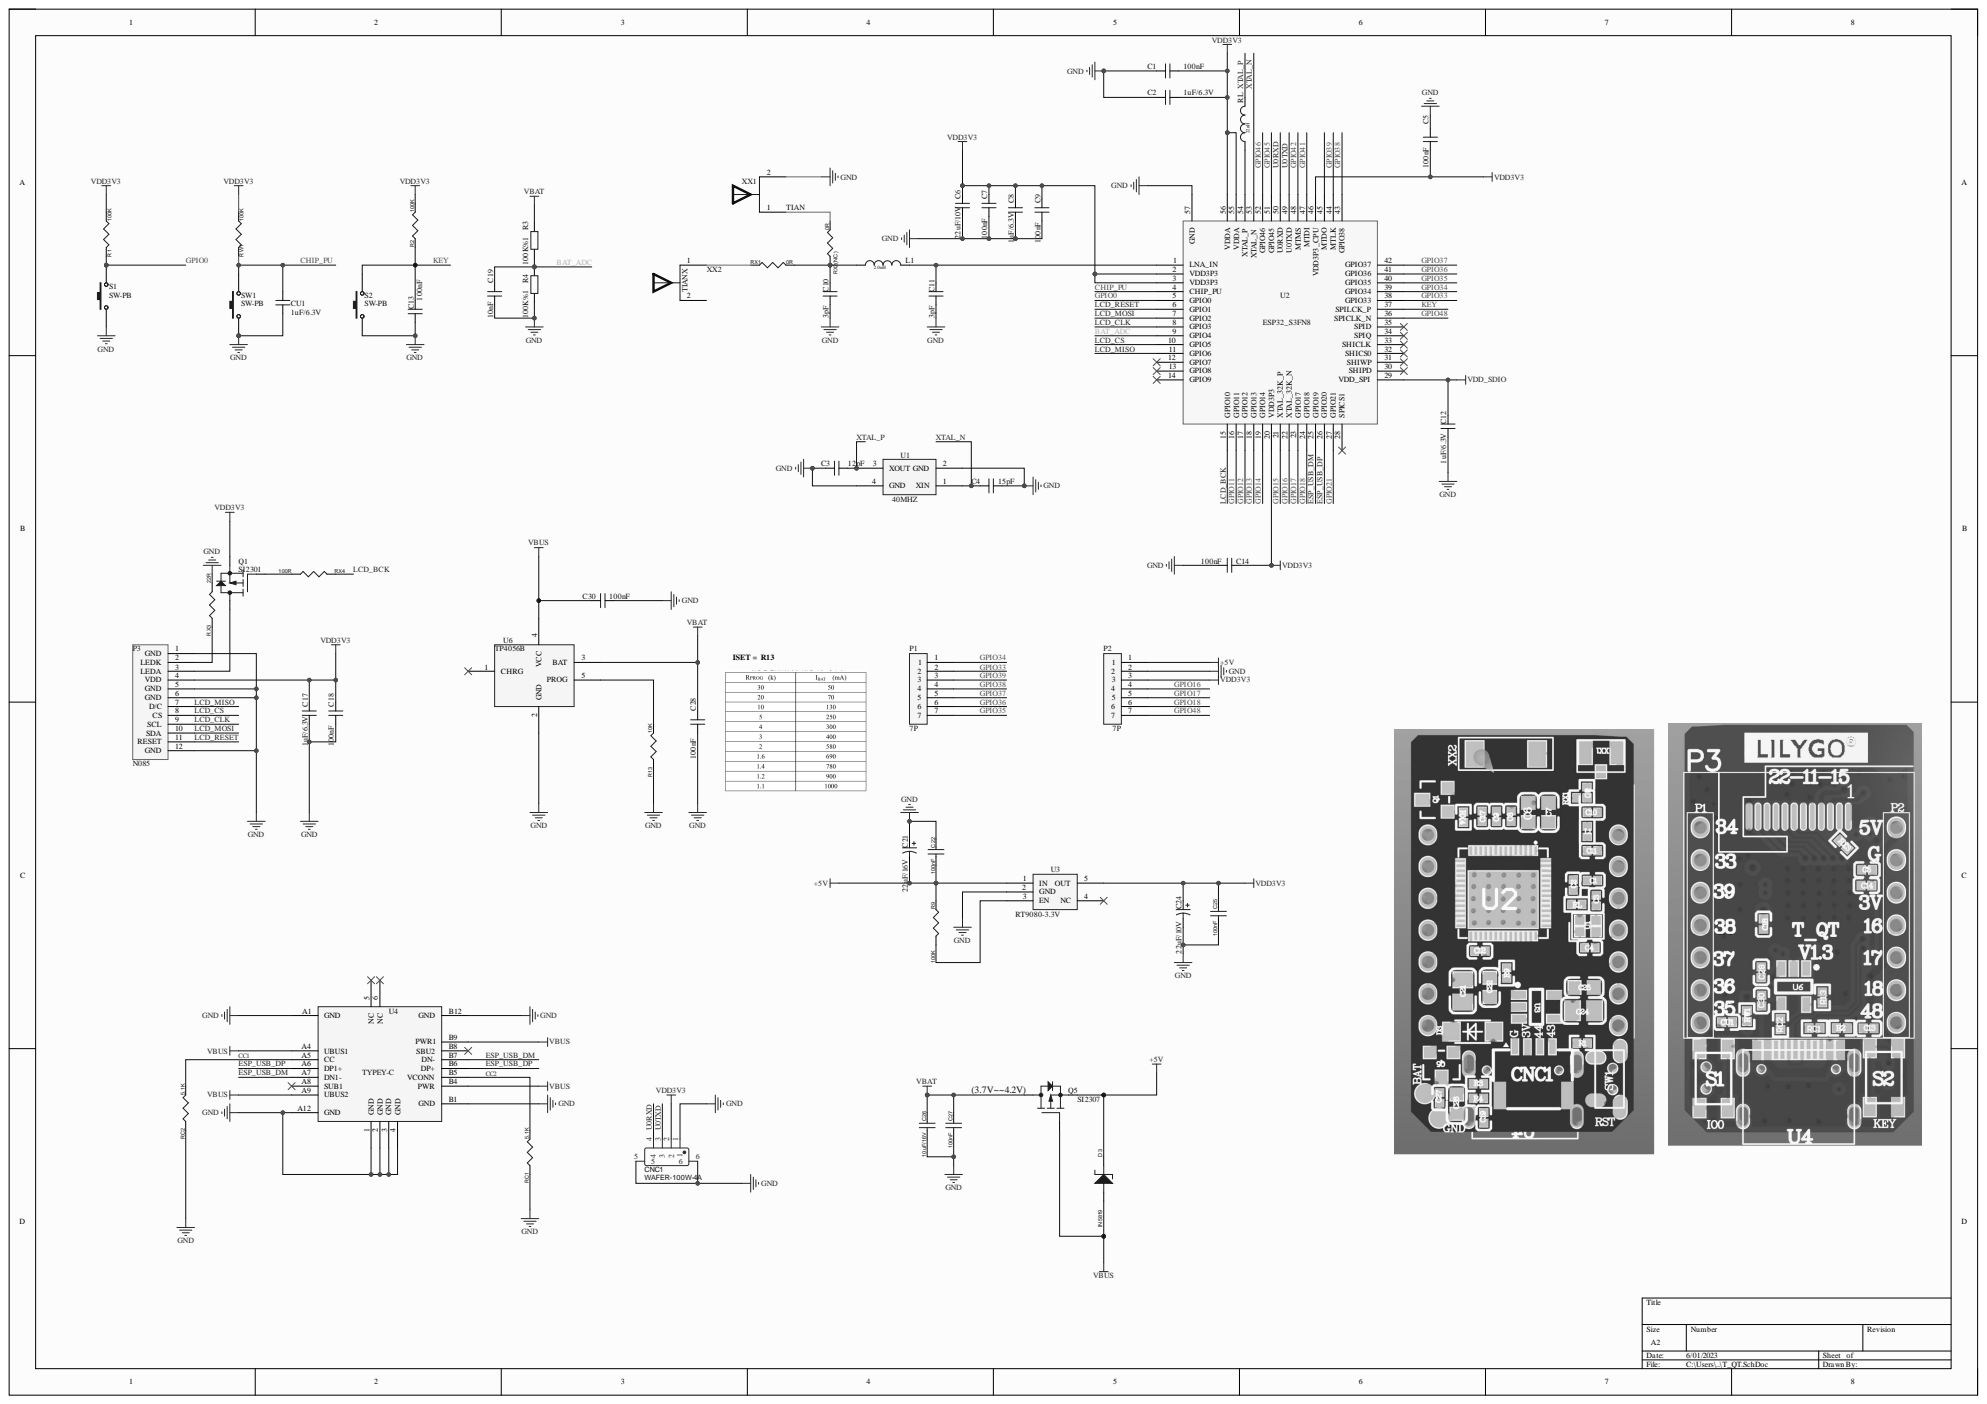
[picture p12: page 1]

GPIO38 43 MTLK 44 MTDO 45 VDD3P3_CPU 46 MTDI 47 MTMS 48 U0TXD 49 U0RXD 50 GPIO45 51 GPIO46 52 XTAL_N 53 XTAL_P 54 VDDA 55 VDDA 56

SPICS1 28 VDD_SPI 29 SHIPD 30 SHIWP 31 SHICS0 32 SHICLK 33 SPIQ 34 SPID 35 SPICLK_N 36 SPILCK_P 37 GPIO33 38 GPIO34 39 GPIO35 40

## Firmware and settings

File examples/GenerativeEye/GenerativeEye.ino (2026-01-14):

/*
 * Generative Eye - Interactive Art for T-QT
 *
 * Abstract organic iris with radial fibers and pulsing pupil
 * Inspired by macro iris photography / sea anemone aesthetics
 *
 * Hardware: LilyGo T-QT Pro (ESP32-S3, GC9A01 128x128)
 */

#include <TFT_eSPI.h>
#include <SPI.h>
#include "OneButton.h"

// Display
TFT_eSPI tft = TFT_eSPI();
TFT_eSprite spr = TFT_eSprite(&tft);

// Screen dimensions
#define SCREEN_W 128
#define SCREEN_H 128
#define CENTER_X 64
#define CENTER_Y 64

// Button pins
#define PIN_BTN_L 0
#define PIN_BTN_R 47

// Buttons
OneButton btnLeft(PIN_BTN_L, true, true);
OneButton btnRight(PIN_BTN_R, true, true);

// Colors
#define COL_BLACK       0x0000
#define COL_WHITE       0xFFFF
#define COL_CYAN_DARK   0x3B6C  // Dark cyan for fiber base
#define COL_CYAN_MID    0x5D12  // Medium cyan
#define COL_CYAN_LIGHT  0x7F18  // Light cyan/pale blue
#define COL_CYAN_PALE   0xAFBF  // Very pale cyan (almost white)
#define COL_ORANGE      0xFB80  // Orange for dots
#define COL_ORANGE_DARK 0xC240  // Darker orange ring
#define COL_RED_DARK    0x9000  // Dark red inner ring

// Fiber parameters
#define NUM_RINGS 12           // Number of concentric rings of fibers
#define BASE_FIBERS 16         // Fibers in innermost ring
#define MAX_FIBERS 400         // Maximum total fibers

// Fiber structure
struct Fiber {
  float angle;        // Base angle in radians
  float length;       // Length from center
  float phase;        // Animation phase offset
  int ring;           // Which ring this fiber belongs to
};

Fiber fibers[MAX_FIBERS];
int numFibers = 0;

// Pupil parameters
float pupilRadius = 18;
float pupilTargetRadius = 18;
float pupilPhase = 0;

// Animation timing
unsigned long lastFrameTime = 0;
float animTime = 0;

// Glitch parameters
unsigned long lastGlitchTime = 0;
#define GLITCH_INTERVAL 10000
bool isGlitching = false;
unsigned long glitchStartTime = 0;
#define GLITCH_DURATION 800

// Text display state
enum DisplayState {
  STATE_EYE,
  STATE_DIGITAL,
  STATE_HUMANITY,
  STATE_FADE_OUT
};
DisplayState currentState = STATE_EYE;
unsigned long stateStartTime = 0;
#define TEXT_DISPLAY_TIME 3000
#define FADE_DURATION 500

// Kinetic text
int textAnimFrame = 0;
unsigned long lastTextAnimTime = 0;

// Glitch characters
const char glitchChars[] = "01!@#$%^&*<>[]{}|/\\~`";
const int numGlitchChars = sizeof(glitchChars) - 1;

// Forward declarations
void onLeftClick();
void onRightClick();
void initFibers();
void drawEye();
void drawGlitch();
void drawDigital();
void drawHumanity();
void drawFadeOut();
void drawKineticText(const char* text, bool whiteBg);

void setup() {
  Serial.begin(115200);

  randomSeed(analogRead(4) * millis());

  // Initialize display
  tft.init();
  tft.setRotation(0);
  tft.fillScreen(COL_BLACK);

  // Create sprite for double buffering
  spr.createSprite(SCREEN_W, SCREEN_H);
  spr.setColorDepth(16);

  // Setup buttons
  btnLeft.attachClick(onLeftClick);
  btnRight.attachClick(onRightClick);

  // Initialize fibers
  initFibers();

  // Initialize timing
  lastFrameTime = millis();
  lastGlitchTime = millis();

  Serial.println("Generative Eye initialized");
}

void initFibers() {
  numFibers = 0;

  // Create concentric rings of fibers
  for (int ring = 0; ring < NUM_RINGS; ring++) {
    // More fibers in outer rings
    int fibersInRing = BASE_FIBERS + ring * 8;
    float ringRadius = 22 + ring * 4;  // Starting radius + spacing

    for (int i = 0; i < fibersInRing && numFibers < MAX_FIBERS; i++) {
      float baseAngle = (2.0 * PI * i) / fibersInRing;
      // Add slight randomness to angle
      baseAngle += ((random(100) - 50) / 50.0) * (PI / fibersInRing) * 0.3;

      fibers[numFibers].angle = baseAngle;
      fibers[numFibers].length = ringRadius + random(6) - 3;
      fibers[numFibers].phase = random(1000) / 1000.0 * 2 * PI;
      fibers[numFibers].ring = ring;
      numFibers++;
    }
  }

  Serial.printf("Created %d fibers\n", numFibers);
}

void loop() {
  unsigned long currentTime = millis();
  float deltaTime = (currentTime - lastFrameTime) / 1000.0;
  lastFrameTime = currentTime;

  // Update animation time
  animTime += deltaTime;

  // Always tick buttons
  btnLeft.tick();
  btnRight.tick();

  switch (currentState) {
    case STATE_EYE:
      // Check for glitch trigger
      if (currentTime - lastGlitchTime >= GLITCH_INTERVAL && !isGlitching) {
        isGlitching = true;
        glitchStartTime = currentTime;
      }

      // Update glitch state
      if (isGlitching) {
        if (currentTime - glitchStartTime >= GLITCH_DURATION) {
          isGlitching = false;
          lastGlitchTime = currentTime;
        } else {
          drawGlitch();
          delay(25);
          break;
        }
      }

      // Update pupil pulsing
      pupilPhase += deltaTime * 0.8;
      pupilTargetRadius = 16 + sin(pupilPhase) * 4;
      pupilRadius += (pupilTargetRadius - pupilRadius) * 0.1;

      drawEye();
      delay(20);  // ~50fps
      break;

    case STATE_DIGITAL:
      drawDigital();
      if (currentTime - stateStartTime >= TEXT_DISPLAY_TIME) {
        currentState = STATE_FADE_OUT;
        stateStartTime = currentTime;
      }
      delay(30);
      break;

    case STATE_HUMANITY:
      drawHumanity();
      if (currentTime - stateStartTime >= TEXT_DISPLAY_TIME) {
        currentState = STATE_FADE_OUT;
        stateStartTime = currentTime;
      }
      delay(30);
      break;

    case STATE_FADE_OUT:
      drawFadeOut();
      if (currentTime - stateStartTime >= FADE_DURATION) {
        currentState = STATE_EYE;
        lastGlitchTime = currentTime;
      }
      delay(20);
      break;
  }
}

void onLeftClick() {
  if (currentState == STATE_EYE) {
    currentState = STATE_DIGITAL;
    stateStartTime = millis();
    textAnimFrame = 0;
    lastTextAnimTime = millis();
  }
}

void onRightClick() {
  if (currentState == STATE_EYE) {
    currentState = STATE_HUMANITY;
    stateStartTime = millis();
    textAnimFrame = 0;
    lastTextAnimTime = millis();
  }
}

// Draw a fiber with gradient and tip dot
void drawFiber(float angle, float innerR, float outerR, float wobble) {
  // Apply subtle wobble animation
  float adjustedAngle = angle + sin(animTime * 2 + wobble) * 0.03;

  float cosA = cos(adjustedAngle);
  float sinA = sin(adjustedAngle);

  // Inner point (near pupil)
  int x1 = CENTER_X + (int)(cosA * innerR);
  int y1 = CENTER_Y + (int)(sinA * innerR);

  // Outer point (tip)
  int x2 = CENTER_X + (int)(cosA * outerR);
  int y2 = CENTER_Y + (int)(sinA * outerR);

  // Draw fiber line with gradient effect
  // We'll draw multiple segments for gradient
  int segments = 4;
  for (int s = 0; s < segments; s++) {
    float t1 = (float)s / segments;
    float t2 = (float)(s + 1) / segments;

    int sx1 = x1 + (x2 - x1) * t1;
    int sy1 = y1 + (y2 - y1) * t1;
    int sx2 = x1 + (x2 - x1) * t2;
    int sy2 = y1 + (y2 - y1) * t2;

    // Color gradient: darker near center, lighter at tips
    uint16_t col;
    if (t1 < 0.25) col = COL_CYAN_DARK;
    else if (t1 < 0.5) col = COL_CYAN_MID;
    else if (t1 < 0.75) col = COL_CYAN_LIGHT;
    else col = COL_CYAN_PALE;

    spr.drawLine(sx1, sy1, sx2, sy2, col);
  }

  // Draw orange dot at tip
  // Outer dark ring
  spr.fillCircle(x2, y2, 3, COL_ORANGE_DARK);
  // Orange middle
  spr.fillCircle(x2, y2, 2, COL_ORANGE);
  // Highlight
  spr.drawPixel(x2 - 1, y2 - 1, COL_CYAN_PALE);
}

void drawEye() {
  // Clear to black
  spr.fillSprite(COL_BLACK);

  // Draw all fibers
  for (int i = 0; i < numFibers; i++) {
    float innerR = pupilRadius + 2 + fibers[i].ring * 0.5;
    float outerR = fibers[i].length;

    // Skip if fiber would be inside pupil
    if (innerR >= outerR - 4) continue;

    drawFiber(fibers[i].angle, innerR, outerR, fibers[i].phase);
  }

  // Draw pupil (jagged edge)
  // First draw a slightly larger circle for the jagged edge effect
  int jaggedPoints = 32;
  int prevX = 0, prevY = 0;
  int firstX = 0, firstY = 0;

  for (int i = 0; i <= jaggedPoints; i++) {
    float angle = (2.0 * PI * i) / jaggedPoints;
    // Add noise to radius for jagged effect
    float noise = sin(angle * 8 + animTime * 3) * 2 + sin(angle * 13 + animTime * 2) * 1.5;
    float r = pupilRadius + noise;

    int x = CENTER_X + (int)(cos(angle) * r);
    int y = CENTER_Y + (int)(sin(angle) * r);

    if (i == 0) {
      firstX = x;
      firstY = y;
    } else {
      // Draw triangles to fill the jagged pupil
      spr.fillTriangle(CENTER_X, CENTER_Y, prevX, prevY, x, y, COL_BLACK);
    }

    prevX = x;
    prevY = y;
  }

  // Draw solid inner pupil
  spr.fillCircle(CENTER_X, CENTER_Y, (int)pupilRadius - 3, COL_BLACK);

  // Circular mask for display edge
  for (int y = 0; y < SCREEN_H; y++) {
    for (int x = 0; x < SCREEN_W; x++) {
      float dx = x - CENTER_X;
      float dy = y - CENTER_Y;
      if (dx*dx + dy*dy > 62*62) {
        spr.drawPixel(x, y, COL_BLACK);
      }
    }
  }

  spr.pushSprite(0, 0);
}

void drawGlitch() {
  unsigned long elapsed = millis() - glitchStartTime;
  float progress = (float)elapsed / GLITCH_DURATION;
  float intensity = sin(progress * PI) * 0.8;

  spr.fillSprite(COL_BLACK);

  int glitchType = random(4);

  switch (glitchType) {
    case 0: {
      // Scattered ASCII
      spr.setTextColor(COL_WHITE);
      int numChars = (int)(intensity * 40) + 5;
      for (int i = 0; i < numChars; i++) {
        int x = random(SCREEN_W);
        int y = random(SCREEN_H);
        char c = glitchChars[random(numGlitchChars)];
        spr.drawChar(x, y, c, COL_WHITE, COL_BLACK, 1);
      }
      break;
    }

    case 1: {
      // Horizontal lines with ASCII
      for (int y = 0; y < SCREEN_H; y += 8) {
        if (random(100) < intensity * 100) {
          spr.drawFastHLine(0, y, SCREEN_W, COL_WHITE);
          for (int x = 0; x < SCREEN_W; x += 12) {
            if (random(100) < 50) {
              char c = glitchChars[random(numGlitchChars)];
              spr.drawChar(x, y - 4, c, COL_BLACK, COL_WHITE, 1);
            }
          }
        }
      }
      break;
    }

    case 2: {
      // Binary rain
      for (int x = 0; x < SCREEN_W; x += 10) {
        int startY = random(SCREEN_H);
        int len = random(3, 8);
        for (int i = 0; i < len; i++) {
          int y = (startY + i * 10) % SCREEN_H;
          char c = random(2) ? '0' : '1';
          uint16_t col = (i == len - 1) ? COL_WHITE : COL_CYAN_MID;
          spr.drawChar(x, y, c, col, COL_BLACK, 1);
        }
      }
      break;
    }

    case 3: {
      // Block distortion
      int numBlocks = (int)(intensity * 8) + 2;
      for (int i = 0; i < numBlocks; i++) {
        int bx = random(SCREEN_W - 30);
        int by = random(SCREEN_H - 15);
        int bw = random(15, 40);
        int bh = random(8, 20);
        uint16_t col = random(2) ? COL_WHITE : COL_CYAN_MID;
        spr.fillRect(bx, by, bw, bh, col);
        char c = glitchChars[random(numGlitchChars)];
        uint16_t textCol = (col == COL_WHITE) ? COL_BLACK : COL_WHITE;
        spr.drawChar(bx + bw/2 - 3, by + bh/2 - 4, c, textCol, col, 1);
      }
      break;
    }
  }

  // Noise dots
  int numDots = (int)(intensity * 100);
  for (int i = 0; i < numDots; i++) {
    spr.drawPixel(random(SCREEN_W), random(SCREEN_H), random(2) ? COL_WHITE : COL_CYAN_MID);
  }

  // Circular mask
  for (int y = 0; y < SCREEN_H; y++) {
    for (int x = 0; x < SCREEN_W; x++) {
      float dx = x - CENTER_X;
      float dy = y - CENTER_Y;
      if (dx*dx + dy*dy > 62*62) {
        spr.drawPixel(x, y, COL_BLACK);
      }
    }
  }

  spr.pushSprite(0, 0);
}

void drawKineticText(const char* text, bool whiteBg) {
  unsigned long currentTime = millis();

  if (currentTime - lastTextAnimTime > 50) {
    textAnimFrame++;
    lastTextAnimTime = currentTime;
  }

  uint16_t bgColor = whiteBg ? COL_WHITE : COL_BLACK;
  uint16_t textColor = whiteBg ? COL_BLACK : COL_WHITE;

  spr.fillSprite(bgColor);

  int len = strlen(text);
  int charWidth = 10;
  int charHeight = 16;
  int totalWidth = len * charWidth;
  int startX = (SCREEN_W - totalWidth) / 2;
  int startY = (SCREEN_H - charHeight) / 2;

  for (int i = 0; i < len; i++) {
    float phase = (textAnimFrame * 0.15 + i * 0.5);
    int offsetY = (int)(sin(phase) * 3);
    int offsetX = (int)(cos(phase * 0.7) * 2);

    char c = text[i];
    if (random(100) < 5) {
      c = glitchChars[random(numGlitchChars)];
    }

    int x = startX + i * charWidth + offsetX;
    int y = startY + offsetY;

    if (!whiteBg) {
      spr.drawChar(x + 1, y + 1, c, COL_CYAN_DARK, bgColor, 2);
    }

    spr.drawChar(x, y, c, textColor, bgColor, 2);
  }

  // Scan lines
  for (int y = 0; y < SCREEN_H; y += 4) {
    uint16_t lineColor = whiteBg ? 0xE71C : 0x1082;
    spr.drawFastHLine(0, y, SCREEN_W, lineColor);
  }

  // Circular mask
  for (int y = 0; y < SCREEN_H; y++) {
    for (int x = 0; x < SCREEN_W; x++) {
      float dx = x - CENTER_X;
      float dy = y - CENTER_Y;
      if (dx*dx + dy*dy > 62*62) {
        spr.drawPixel(x, y, COL_BLACK);
      }
    }
  }

  spr.pushSprite(0, 0);
}

void drawDigital() {
  drawKineticText("DIGITAL", true);
}

void drawHumanity() {
  drawKineticText("HUMANITY", false);
}

void drawFadeOut() {
  unsigned long elapsed = millis() - stateStartTime;
  float progress = (float)elapsed / FADE_DURATION;
  if (progress > 1.0) progress = 1.0;

  spr.fillSprite(COL_BLACK);

  // Fade effect with shrinking circles
  for (int i = 0; i < 20; i++) {
    int size = (int)((1.0 - progress) * (64 - i * 3));
    if (size > 0) {
      uint8_t gray = (uint8_t)((20 - i) * 12 * (1.0 - progress));
      uint16_t col = (gray >> 3) << 11 | (gray >> 2) << 5 | (gray >> 3);
      spr.fillCircle(CENTER_X, CENTER_Y, size, col);
    }
  }

  // Circular mask
  for (int y = 0; y < SCREEN_H; y++) {
    for (int x = 0; x < SCREEN_W; x++) {
      float dx = x - CENTER_X;
      float dy = y - CENTER_Y;
      if (dx*dx + dy*dy > 62*62) {
        spr.drawPixel(x, y, COL_BLACK);
      }
    }
  }

  spr.pushSprite(0, 0);
}

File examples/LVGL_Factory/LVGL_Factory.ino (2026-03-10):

#include "Arduino.h"
#include "OneButton.h"
#include "WiFi.h"
#include "image_logo.h"
#include "img_t_qt_cert.h"
#include "lvgl.h"
#include "lvgl_gui.h"
#include "esp_sntp.h"
#include "time.h"
#include <TFT_eSPI.h>

#define SCREEN_WIDTH         128
#define SCREEN_WIDTH         128

#ifndef WIFI_SSID
#define WIFI_SSID            "Your-ssid"
#endif

#ifndef WIFI_PASSWORD
#define WIFI_PASSWORD       "Your-password"
#endif


#define NTP_SERVER1          "pool.ntp.org"
#define NTP_SERVER2          "time.nist.gov"
#define GMT_OFFSET_SEC       (3600 * 8)
#define DAY_LIGHT_OFFSET_SEC 0


#define PIN_BAT_VOLT         4
#define PIN_BTN_L            0
#define PIN_BTN_R            47
#define PIN_LCD_BL           10


static lv_disp_draw_buf_t draw_buf;
static lv_color_t buf[SCREEN_WIDTH * SCREEN_WIDTH];
OneButton btn_left(PIN_BTN_L, true);
OneButton btn_right(PIN_BTN_R, true);

TFT_eSPI tft =  TFT_eSPI();

#define LV_DELAY(x)                                                            \
  do {                                                                         \
    uint32_t t = x;                                                            \
    while (t--) {                                                              \
      lv_timer_handler();                                                      \
      delay(1);                                                                \
    }                                                                          \
  } while (0);

void disp_flush(lv_disp_drv_t *disp, const lv_area_t *area,
                lv_color_t *color_p)
{
    uint32_t w = ( area->x2 - area->x1 + 1 );
    uint32_t h = ( area->y2 - area->y1 + 1 );

    tft.startWrite();
    tft.setAddrWindow( area->x1, area->y1, w, h );
    tft.pushColors( ( uint16_t * )&color_p->full, w * h, false );
    tft.endWrite();

    lv_disp_flush_ready( disp );
}

void printLocalTime()
{
    struct tm timeinfo;
    if (!getLocalTime(&timeinfo)) {
        Serial.println("No time available (yet)");
        return;
    }
    Serial.println(&timeinfo, "%A, %B %d %Y %H:%M:%S");
}

// Callback function (get's called when time adjusts via NTP)
void timeavailable(struct timeval *t)
{
    Serial.println("Got time adjustment from NTP!");
    printLocalTime();
    WiFi.disconnect();
}

void switch_gui(void)
{
    static uint32_t n;
    n++;
    gui_switch_page(n % 6);
}

void wifi_test(void)
{
    String text;

    lv_obj_t *label = lv_label_create(lv_scr_act());
    lv_obj_align(label, LV_ALIGN_TOP_LEFT, 0, 0);
    lv_obj_set_width(label, LV_PCT(100));
    lv_label_set_text(label, "Scan WiFi");
    lv_label_set_long_mode(label, LV_LABEL_LONG_SCROLL);
    LV_DELAY(1);
    WiFi.mode(WIFI_STA);
    WiFi.disconnect();
    delay(100);
    int n = WiFi.scanNetworks();
    Serial.println("scan done");
    if (n == 0) {
        text = "no networks found";
    } else {
        text = n;
        text += " networks found\n";
        for (int i = 0; i < n; ++i) {
            text += (i + 1);
            text += ": ";
            text += WiFi.SSID(i);
            text += " (";
            text += WiFi.RSSI(i);
            text += ")";
            text += (WiFi.encryptionType(i) == WIFI_AUTH_OPEN) ? " \n" : "*\n";
            delay(10);
        }
    }
    lv_label_set_text(label, text.c_str());
    Serial.println(text);
    LV_DELAY(500);
    text = "Connecting to \n";
    Serial.print("Connecting to ");
    text += WIFI_SSID;
    text += "\n";
    Serial.print(WIFI_SSID);
    WiFi.begin(WIFI_SSID, WIFI_PASSWORD);
    uint32_t last_tick = millis();
    uint32_t i = 0, j = 0;
    while (WiFi.status() != WL_CONNECTED) {
        if (i++ > 40) {
            text += "\n";
            i = 0;
        }
        delay(100);
        text += ".";
        lv_label_set_text(label, text.c_str());
        Serial.print(".");
        lv_timer_handler();
        if (j++ > 200)
            break;
    }
    if (WiFi.status() == WL_CONNECTED) {
        text += "\n CONNECTED \nTakes ";
        Serial.print("\n CONNECTED \nTakes ");
        text += millis() - last_tick;
        Serial.print(millis() - last_tick);
        text += " ms\n";
        Serial.println(" millseconds");
        lv_label_set_text(label, text.c_str());
        LV_DELAY(2000);
    } else {
        text += "\n connection failure  \nTakes ";
        Serial.print("\n connection failure  \nTakes ");
        text += millis() - last_tick;
        Serial.print(millis() - last_tick);
        text += " ms\n";
        Serial.println(" millseconds");
        lv_label_set_text(label, text.c_str());
        LV_DELAY(2000);
    }
}

void go_to_sleep(void)
{
    Serial.println("sleep");

    // High level off the backlight
    digitalWrite(PIN_LCD_BL, HIGH);
    //Enable backlight hold on high level
    gpio_hold_en((gpio_num_t)PIN_LCD_BL);

    //IO47 cannot be set to the source of the awakening,
    //and can only be set to GPIO0 as the keys to wake the source
#if ESP_IDF_VERSION >=  ESP_IDF_VERSION_VAL(4,4,6)
    esp_sleep_enable_ext1_wakeup(GPIO_SEL_0, ESP_EXT1_WAKEUP_ANY_LOW);
#else
    esp_sleep_enable_ext1_wakeup(GPIO_SEL_0, ESP_EXT1_WAKEUP_ALL_LOW);
#endif

    esp_deep_sleep_start();
}

void print_chip_info(void)
{
    Serial.print("Chip: ");
    Serial.println(ESP.getChipModel());
    Serial.print("ChipRevision: ");
    Serial.println(ESP.getChipRevision());
    Serial.print("Psram size: ");
    Serial.print(ESP.getPsramSize() / 1024);
    Serial.println("KB");
    Serial.print("Flash size: ");
    Serial.print(ESP.getFlashChipSize() / 1024);
    Serial.println("KB");
}
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

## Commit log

2022-06-15 first commit
    1. Add sample programs.
    2. Added chip data file.
    3. Added schematic diagram.
    4. Add readme.
2023-01-06 Add and specify board information.
2023-03-28 fix board name
2023-05-16 Add an example of using an external sensor
2023-06-13 Added DXF
    [T_QT.DXF]
2023-10-17 Fix ArduinoIDE 2.0.14 compilation error
    [LVGL_Factory.ino]
2024-04-11 Fixed QWIIC connector pinout in image.
2026-01-14 Add interactive generative eye artwork for T-QT display
    - Creates living eye animation that looks around randomly and blinks naturally
    - Implements ASCII glitch disruption every 10 seconds with varied visual effects
    - Left button displays "DIGITAL" on white background with kinetic text
    - Right button displays "HUMANITY" on black background with kinetic text
    - Both button states last 3 seconds with fade-out transition back to eye
    - Uses double-buffered sprite rendering for smooth 60fps animation
    - Circular masking to match the T-QT's round GC9A01 display
    [GenerativeEye.ino]
2026-01-14 Update eye to organic fiber/tentacle aesthetic
    Completely rewrites the eye visualization to match the reference:
    - Radial fiber structures emanating from center pupil
    - Cyan-to-pale gradient fibers with orange dots at tips
    - Jagged, organic pupil edge that animates
    - Pupil pulsing/breathing animation
    - ~400 fibers arranged in 12 concentric rings
    - Subtle wobble animation on all fibers
    - Maintains all button interactions and glitch effects
    [GenerativeEye.ino]
2026-04-13 Add spiffs example https://github.com/Xinyuan-LilyGO/T-QT/issues/48
    [SPIFFS_Test.ino]
